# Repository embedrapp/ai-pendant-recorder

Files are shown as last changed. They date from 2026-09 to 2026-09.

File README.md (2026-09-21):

# AI Pendant Recorder

An open-source, privacy-first wearable audio recorder built around the Seeed XIAO ESP32S3. It records PDM microphone audio to removable microSD storage and uses a 5 × 5 RGB matrix for low-power status feedback.

## Hardware

- Seeed XIAO ESP32S3 **113991114** controller
- Infineon IM69D130 PDM microphone
- Molex 104031-0811 microSD socket
- MAX17048 fuel gauge and BMI270 IMU
- Regulated haptic output
- 25 × WS2812C-2020-V1 RGB LEDs
- Protected 500 mAh 1S LiPo design target
- No camera or speaker

## Schematics

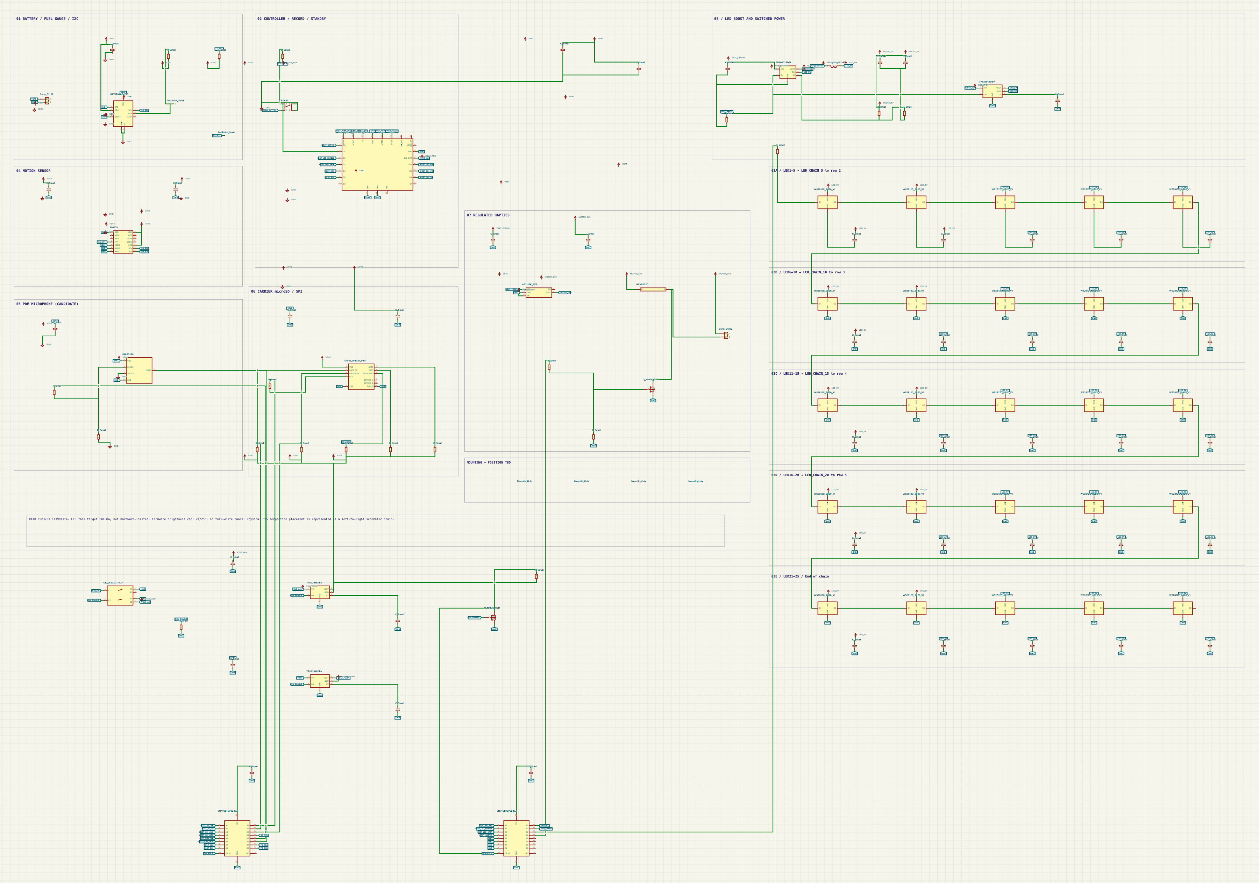
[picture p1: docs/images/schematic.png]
Full project schematic


The schematic is generated from [`pcb/ai_pendant_recorder.zen`](pcb/ai_pendant_recorder.zen) and is organized into battery/fuel-gauge, controller, motion, microphone, storage, haptics, LED power, and LED-row sections. Open the image for the full-resolution view.

## Board

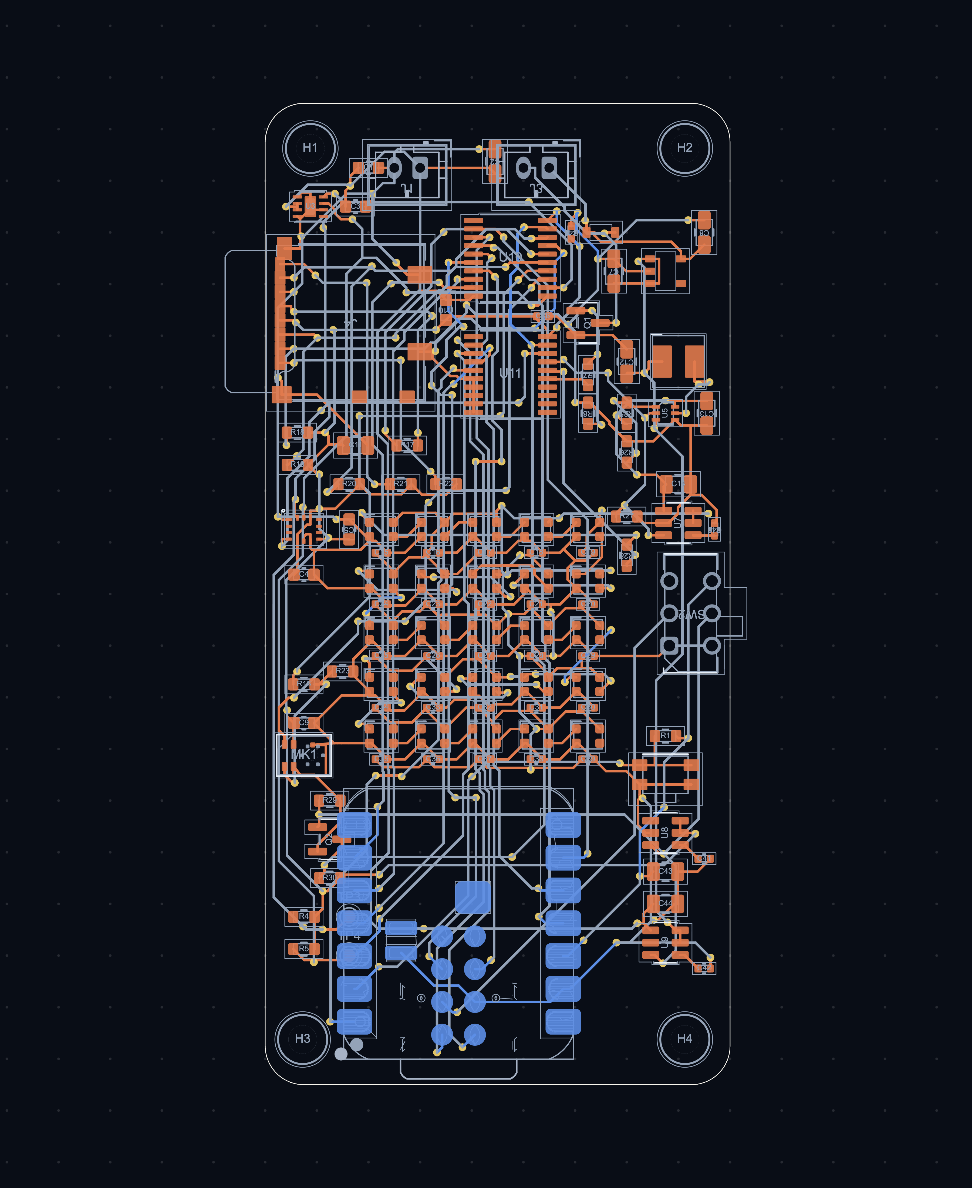
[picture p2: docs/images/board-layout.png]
Current PCB layout


The current four-layer KiCad board is in [`pcb/layout/layout.kicad_pcb`](pcb/layout/layout.kicad_pcb). It has a closed 36 × 76 mm rounded outline, four mounting holes, 115 footprints, 1,264 track segments, 200 vias, and no reported airwires.

Fresh checks on the current board:

| Check | Result |
|---|---|
| Zener source build | Pass — 115 components |
| ERC | Pass — 0 errors, 0 warnings, 79 style advice |
| KiCad DRC | **1 error**, 115 footprint-library configuration warnings |
| PDK-backed DFM | Pass — 0 findings |
| Firmware clean build | Pass for `seeed_xiao_esp32s3` |
| Enclosure CAD build | Pass — 16 valid solids |

The remaining DRC error is a 0.21 mm clearance between the IM69D130 acoustic opening and its surrounding ground pad, below the board-wide 0.25 mm hole-clearance rule. The geometry follows Infineon's recommended 0.8 mm sound port and SMD ground-pad land pattern, but the exception still needs an explicit KiCad rule or footprint-level resolution before the PCB checks are fully clean. The library warnings are caused by the standalone KiCad checker not loading the project-managed footprint libraries; they are not geometry violations.

## Mechanical design

### Pendant enclosure

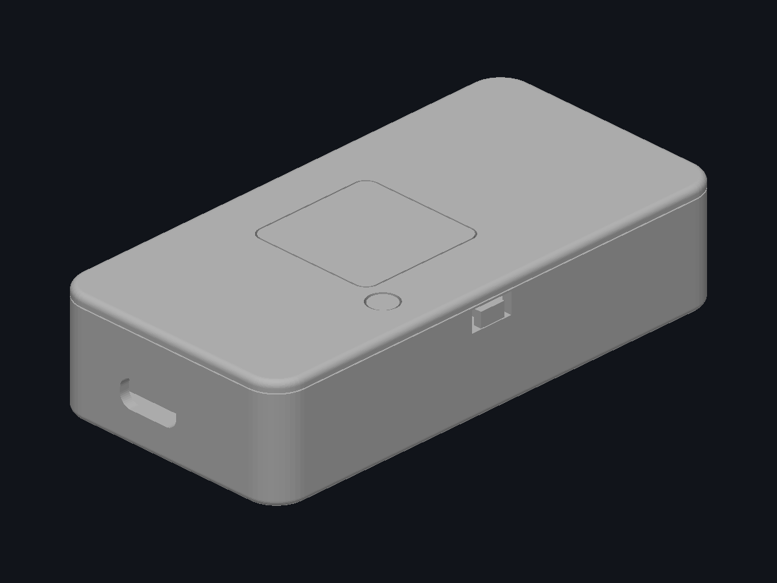
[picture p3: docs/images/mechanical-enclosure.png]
Pendant enclosure CAD


The parametric enclosure includes a rounded two-part shell, front optical area,
record-button opening, side controls/access, and lanyard loop. The latest STEP
build contains 16 valid solids and measures 40 × 87.785 × 18.2 mm overall,
including the loop.

### Populated PCB model

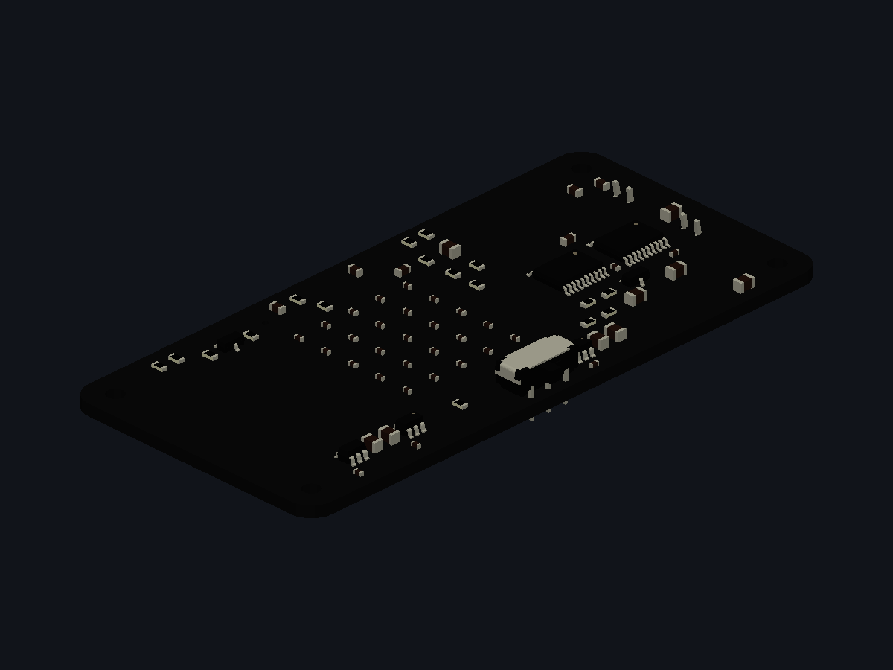
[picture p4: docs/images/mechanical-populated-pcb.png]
Populated PCB mechanical model


The populated-board model is used to coordinate PCB and enclosure geometry.
Some component models and exact interface heights remain incomplete, so the
render is a design aid rather than proof of interference-free physical fit.

## Firmware

The Arduino/PlatformIO firmware currently provides:

- push-to-toggle 16-bit PDM audio capture;
- chunked WAV recording to FAT32 microSD;
- recovery of interrupted `.part` recordings at startup; and
- conservative idle/recording animations on the RGB matrix.

Wi-Fi upload, fuel-gauge monitoring, motor activation, and automatic file deletion are not implemented.

### Build

1. Install [PlatformIO](https://platformio.org/).
2. Clone this repository and enter it.
3. Build the default environment:

   ```sh
   pio run
   ```

4. Connect a Seeed XIAO ESP32S3 and upload:

   ```sh
   pio run --target upload
   pio device monitor --baud 115200
   ```

Use a qualified FAT32 microSD card. Hardware pin assignments are documented in [`docs/current-design.md`](docs/current-design.md); setup notes are in [`docs/setup.md`](docs/setup.md).

## Repository map

| Path | Purpose |
|---|---|
| `src/main.cpp` | Recorder firmware entry point |
| `include/` | Shared firmware configuration and WAV helpers |
| `tests/` | Host-side audio-format test |
| `pcb/ai_pendant_recorder.zen` | Electrical and connectivity source |
| `pcb/layout/` | Current KiCad PCB and schematic |
| `pcb/bom.json` | Structured generated BOM |
| `docs/bom.md` | Human-readable procurement notes |
| `mechanical/` | Parametric enclosure source and current PCB STEP import |

## Engineering status

The current source, PCB, firmware, and enclosure generators are maintained together and were freshly built or checked. Remaining hardware work is tracked in [`docs/current-design.md`](docs/current-design.md), including the microphone DRC rule, power and charging validation, exact motor selection, enclosure interface dimensions, and physical bench testing.

## Contributing

Issues and pull requests are welcome. Keep changes focused, identify the hardware revision they target, and include validation evidence where practical. Do not commit credentials, private recordings, generated build directories, or unreviewed manufacturing outputs.

## License

This project is intended to be open source, but no license file is currently present. Until the maintainers add one, copyright law reserves reuse rights; please open an issue before redistributing or incorporating the design.

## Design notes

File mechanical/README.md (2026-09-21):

# Pendant enclosure

The maintained enclosure is generated from `pendant.py` using `pendant.cad.json`. It consumes the current board at `pcb/layout/layout.kicad_pcb`.

## Current geometry

Fresh cloud build and STEP inspection succeeded at revision `rev-db67b8b5fdb57ca66d4f7f5087f22955316bc1564d08ab42042626d73e8636f6`:

- 16 valid solids;
- overall measured bounds: 40 × 87.785 × 18.2 mm, including the lanyard loop;
- PCB frame: 36 × 76 × 1.62 mm with four 2.2 mm mounting holes;
- wearing orientation: lanyard at +Y, USB at -Y, LED face at +Z, and battery side at -Z.

The assembly includes the rear chassis, front cover, removable battery sled, optical cassette, 25-well optical baffle, record key, standby slider, acoustic gasket, and component reference envelopes. The detailed KiCad PCB STEP remains available as the separate `populated-pcb` mechanical design.

## Design assumptions

- PA12 additive manufacture is the current prototype process assumption.
- Battery envelope is 30.1 × 36 × 5.1 mm with 6.1 mm reserved thickness.
- USB and switch heights, mated connector/cable bends, antenna volume, exact motor package, and fastener selection are not yet established from complete manufacturer geometry.
- Four rear-access M2-class clearance bores and 1.6 mm blind pilot holes are modeled; screw length and pilot fit need a physical trial.

## Remaining fit validation

- Verify battery identity, swelling allowance, PCM and lead dimensions.
- Verify microSD insertion direction and the full card/finger access envelope.
- Verify USB plug overmold reach, switch travel, JST cable routing, and antenna clearance.
- Add or verify missing component 3D models and exact component heights.
- Check pairwise interference, tolerances, tool access, removal paths, enclosure closure, sealing, pull strength, and fatigue.
- Prototype the enclosure and perform an assembled hardware fit check.

A valid STEP build establishes solid geometry and measured bounds; it does not by itself establish tolerance, strength, sealing, or physical fit.

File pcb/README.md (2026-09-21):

# Electronics workspace

The maintained electrical source is `ai_pendant_recorder.zen`; the current physical board is `layout/layout.kicad_pcb`.

Sourcing metadata is stored in the source `PURCHASE_LINKS` / `DATASHEET_INDEX` maps and the persisted `bom.json` overlay. `bom.csv` is generated and should not be hand-edited.

## Board

- 36 × 76 mm rounded outline
- four copper layers, modeled at 1.62 mm total thickness
- 115 footprints
- 1,264 track segments and 200 vias
- no zones and no reported airwires

The source `Board(...)` points to `layout`, so there is one active board location. Regenerating or synchronizing a routed PCB is a deliberate board mutation; preserve and compare copper before doing so.

## Current checks

- Source build: pass, 115 components.
- ERC: pass, 79 style advice entries.
- DRC: one IM69D130 acoustic-hole/ground-land clearance error plus footprint-library configuration warnings.
- PDK-backed DFM: pass with no findings.

The microphone geometry follows Infineon's recommended 0.8 mm PCB sound port and surrounding solder-mask-defined ground land. Represent that intended geometry with a local KiCad rule or reviewed footprint change; do not weaken the global hole-clearance rule.

The four-layer stackup is a project model rather than a controlled-impedance fabricator stackup. Review boost current loops, trace widths, return paths, and the absence of copper planes before fabrication.

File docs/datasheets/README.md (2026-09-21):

# Datasheet evidence

Project document registrations are in `../../embedr.yaml`. Indexed documents
and exact part mappings are recorded in the Zen source. Local PDFs in this
directory support current components; check the manufacturer revision before
using them as procurement or production evidence.

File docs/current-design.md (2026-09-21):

# Current design status

The maintained design consists of:

- electrical source: `pcb/ai_pendant_recorder.zen`;
- current four-layer board: `pcb/layout/layout.kicad_pcb`;
- firmware: `src/main.cpp`; and
- enclosure generator: `mechanical/pendant.py`.

## Firmware and pin map

The firmware implements PDM recording to microSD and dim LED animations. Radio upload, fuel-gauge monitoring, and motor activation are not implemented.

| XIAO pin | GPIO | Function |
|---|---:|---|
| D0 | 1 | Motor gate |
| D1 | 2 | Record button |
| D2 | 3 | Boost EN / LED switch ON |
| D3 | 4 | LED data |
| D4 / D5 | 5 / 6 | I2C SDA / SCL |
| D8 / D9 / D10 | 7 / 8 / 9 | SD clock / MISO / MOSI |
| MTCK | 39 | SD CS |
| MTDO | 40 | IMU interrupt |
| MTDI / MTMS | 41 / 42 | PDM data / clock |

SW2 holds reset; it is not battery isolation. The battery design target is the protected Adafruit 1578 500 mAh 1S cell, documented with a 500 mA continuous discharge limit. The LED rail target is 100 mA rather than a hardware current limit. Brief dim animations must be coordinated with other loads; the firmware interlock is only partially implemented.

## Fresh validation

Checks were run against the current source and board:

- Zener build: pass, 115 components.
- ERC: pass with 0 errors, 0 warnings, and 79 style advice entries.
- KiCad DRC: 1 error and 115 footprint-library configuration warnings.
- PDK-backed DFM: pass with 0 findings.
- Board connectivity view: 1,264 track segments, 200 vias, and 0 airwires.
- Firmware clean build: pass for `seeed_xiao_esp32s3` / `esp32-s3`.
- Enclosure CAD: build and STEP inspection pass with 16 valid solids; measured bounds are 40 × 87.785 × 18.2 mm including the lanyard loop.

The DRC error is at MK1: the IM69D130's 0.8 mm acoustic opening is 0.21 mm from its surrounding GND land, below the board-wide 0.25 mm hole-clearance rule. Infineon's datasheet recommends the 0.8 mm PCB sound port and the surrounding solder-mask-defined ground land used by the footprint. The board still needs a deliberate footprint-specific KiCad rule or a reviewed footprint adjustment so this intended geometry is represented without a global clearance waiver.

The 115 DRC warnings report footprint libraries unavailable to the isolated KiCad checker. The footprints are embedded in the board and the Zener packages build successfully, so these warnings are configuration provenance warnings rather than reported copper or courtyard violations. They should still be eliminated from a final manufacturing handoff by packaging the library tables with the board export.

## Board and power

The PCB outline spans X=82..118 mm and Y=44..120 mm: 36 × 76 mm with 3 mm rounded corners and four 2.2 mm mounting holes. It is a four-layer board with a 1.62 mm modeled stackup. No copper zones are present, so the routed return paths require engineering review rather than assuming continuous reference planes.

U9 gates only the boost/motor branch (`VBAT_PERIPH`). J1, the XIAO battery input, and the fuel gauge remain on `VBAT`. SW2 carries control current only. USB charging remains connected; USB data operation is not promised while ESP32 EN is grounded.

## Remaining engineering work

- Resolve the microphone hole-clearance DRC rule locally and rerun DRC.
- Review boost hot-loop geometry, power widths, return paths, and four-layer stackup with the selected fabricator.
- Validate charger/regulator behavior, backfeed and power transitions on the bench.
- Select and verify the exact motor, including start/stall current and harness.
- Implement and test low-battery behavior, fuel-gauge monitoring, and haptics.
- Verify battery, USB, switch, connector, antenna, cable, and component-height clearances in a physical enclosure prototype.
- Perform audio, SD-write, thermal, charging, LED sequencing, and runtime recovery tests on assembled hardware.

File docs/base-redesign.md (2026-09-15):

# Superseded reference

Historical content: [archive](archive/pre-bom-finalization/base-redesign.md). Use [current BOM](bom.md), [LED contract](rgb-matrix.md), and the current Zen source. Historical checks do not release this revision.

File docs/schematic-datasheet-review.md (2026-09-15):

# Superseded reference

Historical content: [archive](archive/pre-bom-finalization/schematic-datasheet-review.md). Use [current BOM](bom.md), [LED contract](rgb-matrix.md), and the current Zen source. Historical checks do not release this revision.

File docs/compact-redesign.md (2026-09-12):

# Compact redesign — active engineering checkpoint

## RGB/haptic integration — newest checkpoint

The previous missing-RGB/haptic statements below are historical. Both circuits
are now integrated; see [rgb-haptics.md](rgb-haptics.md) for exact mapping,
datasheet corrections and remaining engineering limits. Source builds with 43
components/65 nets. ERC passes with 0 errors, 0 warnings, 70 naming-only advice
entries (`style.redundant_name`). Pin/net renderer inspection confirms separate
LED resistor nets, regulated motor positive, low-side Q1 and flyback polarity.
Screenshot review still finds long crossings and crowded labels; 29 rendered
envelope overlaps remain, with zero body overlaps. This is not drawing-readability
or physical-assembly acceptance. Existing board remains untouched, stale and
unrouted (33 DRC missing connections, two warnings). Firmware unchanged by request.

## Latest schematic validation checkpoint (supersedes older checkpoints below)

- Integrated bare BMI270 U4 and separate C4/C5 100 nF bypass capacitors.
  Local symbol/14-land footprint follows Bosch DS000-08 pp135,137,143,145.
  Both supply pins connect to 3.3 V; both grounds to GND; CSB high; SDO low;
  auxiliary and interrupt pins NC. Physical footprint review remains open.
- Corrected MAX17048 CELL to protected BAT+ following the manufacturer p6
  instruction, despite its internally unconnected implementation. Updated BOM.
- Package sync and source build pass: 24 components, 39 nets. Renderer pin
  inspection shows U1 D4/U3 SDA/U4 SDx on FG_SDA, U1 D5/U3 SCL/U4 SCx on
  FG_SCL, R4/R5 supply ends on V3V3. The screenshot's apparently floating
  pull-up rail is not a source disconnection, but its presentation needs repair.
- Independent check reports ERC 0 errors/0 warnings, 49 advice entries, all
  `style.redundant_name`. These are naming advice, not electrical failures.
  Existing unsynchronized physical board reports 33 missing connections and
  two warnings; it is NOT the new schematic's validated physical implementation.
- Schematic screenshots now work. Visual review still finds crowded labels,
  unreadable passive values and long crossings; after one broad placement pass
  the renderer reports 15 envelope overlaps (zero component-body overlaps).
- RGB indicators/PWM driver and regulated haptics remain missing. PCA9685PW
  assets and AO3400A package were obtained for evaluation, not integrated or
  approved as compact final selections. AP2112 library metadata gives suspect
  EN/GND numbering and must be compared to manufacturer data before use.
- Firmware/board remain unchanged and incompatible with AMP_ENABLE on D2.
  This is partial progress, not completion or assembly approval.

This redesign supersedes the camera-free direction in historical status notes.
Retain the exact XIAO Sense camera/microphone/microSD stack, bottom USB-C,
onboard charger, bare MAX17048 and BMI270, two RGB indicators, physical controls,
speaker, motor, shutter, and reinforced external loop. Firmware is not being
silently reverted to the original generic DevKit target.

## Constraints and acceptance

- Battery checkpoint: the active tray now targets stocked Adafruit product 1578,
  a protected 1S 3.7 V 500 mAh pack with JST-PH. CAD reserves a conservative
  30.1 x 36.0 x 6.1 mm envelope (5.1 mm maximum documented body plus 1 mm
  expansion allowance). See `mechanical/front-battery-notes.md`. This supersedes
  the older 34 x 50 x 6 mm provisional tray statements below; purchase and
  electrical/thermal validation remain open.
- Compactness is a priority, but no final envelope is accepted yet. The selected
  battery body is approximately 30 x 36 x 5 mm; the old 26 × 42 mm tray cannot fit it.
- Start with two copper layers and top-side assembly; reconsider sides only with
  explicit battery, solder-tail, and module-stack clearance checks.
- Preserve the existing board before synchronization. Initial board SHA-256:
  `603e4063f2eb6049fc6aba0b6d4d31e2fab530e9a42179f2f1ad86a098743166`.
  Inspection found 15 footprints including four holes, no tracks/vias/zones,
  and screenshot reported 33 airwires. Existing locks are not placement approval.
- Keep an antenna wall zone and cable bend space clear of battery, copper,
  speaker/motor magnets, fasteners, and attachment hardware. Target 3–5 mm
  electronics clearance subject to assembled RF tests.
- Printed modules: rear shell, front shell, replaceable shutter and retainer,
  removable battery tray, speaker retainer, motor cradle, light-port inserts,
  optional clothing backer. Final process/tolerances remain to be validated.
- Acceptance requires source/netlist review, visual schematic review, placement
  geometry and images, ERC/DRC/DFM, current assembly STEP interference and service
  path checks, and printed/hardware validation. No release claim from a build.

## Findings to resolve before layout freeze

1. U3/U4, RGB LEDs, haptic circuit, J3 and new support parts are absent from Zen.
2. C1/C2 sourcing differs from the procurement BOM. R3 is amplifier-enable series
   resistance in the source, not an LED resistor. The price table counts four
   100 kΩ resistors for R1/R2/R8 although those references total three.
3. RGB channels require six current-limiting resistors and a GPIO/PWM budget;
   do not allocate camera, microphone or microSD pins to these functions.
   A shared-I2C PWM driver may be needed and would be a documented BOM addition.
4. QX-1027 is rated 2.5–3.5 V (datasheet p3), 85 mA running maximum and 230 mA
   starting/locked maximum at 3 V (p4). Direct 4.2 V BAT+ is not approved.
   Resolve a regulated motor supply and transient/current budget; PWM alone is
   not proof of voltage compatibility. D1 cathode must follow MOTOR+.
5. Superseded: the retained NOVA/LiPol three-wire drawing is no longer the active
   tray basis. Adafruit 1578 is the selected two-wire JST-PH protected candidate;
   delivered-pack polarity, PCM details, shipping and sample metrology remain gates.
6. The retained motor drawing is QX-1027-3.0-07, not proof of the Robu part.
   Model it as a reference variant, not a confirmed purchased component.
7. SW1 GK has neither pegs nor the ESD pin. Use the exact variant in its model.
8. Seeed retained datasheet p6 gives 21 × 17.8 × 15 mm with expansion board;
   the existing enclosure's assumed 10 mm stack is not accepted for this redesign.

## Local reference provenance

- PTS841 PDF SHA-256: `7c9c6ab89d64f98dcc287a2646c8fdceb7bc00973e170807c5de820f69a716bf`, p2.
- LiPol PDF SHA-256: `46d1f33d6de0c5ff81b80471a1f5973744574150349fc1152e5967f51f017052`, p1.
- QX motor PDF SHA-256: `636a2f1f12dba6d8a8be3817c067e20b3dcb9d23b5924e11af8e5077d5cb5a22`, pp3–4,9.

Status: inspection/reconciliation in progress; final assembly is not validated.

## Implemented checkpoint

### Schematic update checkpoint

Added U3 MAX17048 polling circuit, C3 bypass, R4/R5 shared 3.3 V I2C pull-ups,
and TP3/TP4. D4/D5 now carry I2C; AMP_ENABLE moved to D2. Existing firmware
and physical board are NOT synchronized to that pin change and must not be used
as a matched revision. Camera/microphone/microSD remain internal to U1.

Sync and root build passed with 21 components; netlist inventory inspected.
U3 uses the materialized library footprint provisionally: its description cites
an ST DFN package, so comparison with ADI land pattern 90-0065 is a release gate.
The datasheet pin table calls CELL internally unconnected but also says connect
to battery; this draft retains the BOM's NC choice pending reconciliation.

Saved agent-chosen positions for all 21 schematic components. Renderer reports
zero body overlaps but 15 rendered overlaps (including power symbols and labels).
Both screenshot attempts returned blank images despite nonzero component/wire
counts. Visual review is blocked; no schematic-readability acceptance is claimed.
BMI270, RGB indicators/PWM support and regulated motor circuit are still absent.
The full original-plan schematic request is not complete.

- C1/C2 Zen MPNs now match bom.md. Obsolete supplier SKUs were removed rather
  than transferred to different parts. Automatic lint/evaluation and the managed
  root build passed (15 components). No board regeneration or physical move ran.
- MAX17048 symbol/footprint assets materialized with provenance; wrapper and
  fixture validation are still pending. These are not yet integrated into Zen.
- Three preliminary reference STEP exports were cloud-built after repairing
  the Compound construction. All passed inspectable-solid checks only:
  - BAT1: `mechanical/components/bat1-reference/bat1-provisional-envelope.step`,
    revision `rev-31d573a35125bc3859d77bfbb0df98f03f3f52e703582cbb0b0603a178b34017`.
  - M1: `mechanical/components/m1-reference/qx-1027-reference-envelope.step`,
    revision `rev-04c4ff6a515c47ffbbf41770e17c54fde9752942c8d631e716872e359b7e279b`.
  - SW1: `mechanical/components/sw1-reference/pts841gk-body-only.step`,
    revision `rev-3d8be8e52fd355475e70c1d510022c33aa46fd0339a5aa678c6197930127afcf`.
- These are envelope references, not completion of the three detailed CAD gaps.
  SW1 actuator/leads, motor lead exit and purchased battery details remain open.
- Still required: complete GPIO/PWM allocation and motor supply, exact new part
  packages, all BOM support components, schematic layout, compact board outline
  and reviewed placement, modular enclosure/shutter, all-component assembly
  transforms and interference/service sweeps, electrical and printed validation.

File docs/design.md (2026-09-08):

# AI Second Brain pendant — engineering record

The exact XIAO ESP32S3 Sense (SKU 113991115) provides the ESP32-S3, digital microphone, camera connector, and microSD socket. The local MAX98357AETE+T wrapper provides I2S speaker output with 100 nF and 10 uF bypass capacitors. Firmware separates recording and upload FreeRTOS tasks; 15-second chunk files remain local when Wi-Fi is unavailable.

The microphone is the integrated PDM microphone on U1's Sense expansion board: GPIO41 is PDM data and GPIO42 is PDM clock. It is not a separate PCB footprint. Firmware initializes it through Arduino `I2S` in mono PDM mode at 16 kHz/16-bit.

Open hardware decisions: protected LiPo vendor/MPN and dimensions; exact 8-ohm speaker MPN, diameter, thickness, and acoustic volume; final slide switch and battery mating lead; hard EN power-isolation circuit; PCB outline, magnet, standoffs, and enclosure dimensions. The first concept assumes a protected 3.7 V 500 mAh cell.

The DevKitC-1 firmware target is compatibility-only because the installed target catalog has no exact XIAO target. The current firmware is a buildable scaffold, not a completed cloud protocol implementation.

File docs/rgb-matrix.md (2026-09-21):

# Central 5x5 RGB matrix

The speaker-output chain is removed. The board now has a square 5x5 matrix of
25 Worldsemi `WS2812C-2020-V1` addressable RGB LEDs, intended for the visual
thinking/orbit animations in the supplied reference image.

## Electrical implementation

- LED1–LED25 form one 800 kbit/s GRB daisy chain. XIAO D3/GPIO4 drives the
  first pixel through R28 (470 ohm).
- U5 TPS61023 boosts protected `VBAT` to `BOOST_5V` using the TI reference values:
  L1 1 uH, R25 732k, R26 100k, C12 10 uF input, C13/C14 22 uF output.
  The divider gives 4.95 V at the 595 mV typical FB reference
  (`0.595*(1+732/100)`), approximately 4.83–5.08 V across the datasheet's
  580–610 mV PWM reference limits before resistor tolerance. This remains
  inside the LED's documented 3.7–5.3 V operating range.
- U7 TPS22918DBVR switches `BOOST_5V` to the pixel `LED_5V` rail. Its ON pin
  shares XIAO D2/GPIO3 with U5 EN, R27 holds both off through reset, C40=1 nF
  C0G sets about 2.9 ms nominal 5 V rise time, and QOD is tied to `LED_5V` for
  defined discharge. C13/C14 remain on the boost side; per-pixel bypass is on
  the switched side. Firmware holds DATA low before enabling the rail.
- Each pixel has a local 100 nF 0402 capacitor (C15–C39), as required by the
  Worldsemi typical application.

The exact LED is the low-current 5 mA/channel `WS2812C-2020-V1`, LCSC
`C2976072`. Its documented operating range is 3.7–5.3 V and VIH is at least
2.7 V at 5 V, so the XIAO's 3.3 V GPIO directly satisfies the specified input
threshold. Package pinout is DO1, GND2, DI3, VDD4.

## Power limits

The selected Adafruit 1578 / PKCELL protected 500 mAh pack is limited to 1C,
or 500 mA maximum continuous discharge. A theoretical 25-pixel full-white
frame is 375 mA at 5 V before quiescent and conversion losses, which exceeds
the battery budget once the XIAO, storage, microphone, and motor are included.
Firmware must apply a conservative global brightness/current cap, avoid
full-white frames, and inhibit high LED load during motor start. This is an
acceptance requirement, not yet a bench-verified current limit.

Current firmware uses an Adafruit NeoPixel global brightness cap of 24/255,
lights at most five pixels in the recording pulse and one pixel in the idle
orbit, and keeps the haptic gate low by default. The cap is a conservative
software guard, not a substitute for measuring battery, boost, switch and PCB
temperature at minimum battery voltage and worst-case card-write load.
The confirmed product target is no more than 100 mA on the 5 V LED rail.

## Physical intent

### LED-control implementation update

- Animator alone owns data and rail switching after setup. Storage faults request
  FAULT instead of cutting power concurrently with a transmission.
- Startup holds data low, enables the rail, waits a provisional 10 ms, sends
  black, and waits 2 ms before animation. Shutdown sends black, holds data low,
  waits 2 ms, then removes power; no transmissions occur while powered off.
- The 24/255 cap and one/five-pixel animations remain. Recording output is halved
  conservatively for SD load. LED_INHIBIT/LED_OFF provide a request/acknowledgment
  contract for future motor control; HEAVY_LOAD dims future radio activity.
  Motor and radio activity are not currently implemented.
- Low-battery automatic inhibition is NOT implemented: the fuel-gauge driver and
  measured cutoff/recovery thresholds remain required. Do not invent a voltage
  threshold or treat firmware as enforcing measured 100 mA rail current.
- The schematic now reads as five left-to-right rows, preserving exact chain
  connectivity. Physical layout, copper, and component selection are unchanged.
- The configured firmware target is the Seeed XIAO ESP32S3. The clean firmware
  build passes; hardware behavior still requires bench validation.

Place the LEDs as a geometrically regular 5x5 square at board center, with
uniform pitch and identical orientation. Place each bypass capacitor directly
beside its pixel. Keep U5/L1 and their high-current switching loop outside the
microphone acoustic/clock area. The current board uses a regular 5x5 placement;
verify alignment against the enclosure light guide on the physical prototype.

## Evidence

- WS2812C-2020-V1 indexed datasheet: `ds_f7eaed7171762f8cbf8e`
- TPS61023 indexed datasheet: `ds_c3d679f9c6eab3a775cd`
- TPS22918 indexed datasheet: `ds_61aa790c3c3008f98c5e`
- Adafruit 1578 / PKCELL pack: `ds_dcee32f4e0c985211bc8`
- XEL4030 family: `ds_293e09d408f8109bb968`

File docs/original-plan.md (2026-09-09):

# AI Second Brain Pendant — Updated Product Plan

This file records the current product direction. It supersedes the original
camera-based XIAO ESP32S3 Sense-stack concept. Existing PCB, firmware, and
mechanical artifacts still represent earlier revisions in places; this plan is
not evidence that the redesign has been implemented or validated.

## Product goal

Build a thin, tall, narrow wearable audio recorder centered on:

- High-quality voice capture.
- Reliable local storage.
- USB-C programming and single-cell LiPo charging through the controller board.
- Battery percentage reporting.
- Motion/context sensing.
- Optional local speaker playback and haptic feedback.

The camera is no longer a requirement. Remove the camera, camera connector,
camera apertures, privacy shutter, camera power rails, image capture firmware,
and image-upload backend requirements.

## Confirmed architecture

- Use the **base Seeed Studio XIAO ESP32S3 board**, without the Sense camera/SD
  expansion board.
- Preserve the XIAO's working ESP32-S3, flash/PSRAM, USB-C programming, onboard
  LiPo charger, boot/reset circuitry, and Wi-Fi/BLE antenna implementation.
- Create a thin custom carrier PCB that reproduces only the functions needed by
  this product: digital microphone, storage, sensors, indicators, audio, and
  haptics.
- Do not mount the XIAO on pin headers. Use low-profile direct soldering or a
  recessed/cutout arrangement after verifying accessible pads and assembly
  clearances.
- Keep the battery, XIAO, speaker, and motor in separate XY regions where
  possible. Do not stack the PCB or tall components over the LiPo pouch.
- Keep the speaker and vibration motor for the first integrated prototype;
  remove either only if measured fit, runtime, acoustic, or peak-current results
  require it.

## Controller and USB

- Confirm the exact orderable base-XIAO part identity and its current schematic,
  pad map, dimensions, and antenna requirements before changing the PCB source.
- Use the XIAO USB-C connector for both programming and charging.
- Retain access to boot/reset and provide production test points where practical.
- Do not drive USB VBUS from another 5 V source.
- Treat the onboard charger as a simple charger, not a full power-path manager.
  Measure whether the system can operate and charge acceptably at the same time.
- If authoritative charge/full/fault reporting becomes mandatory, a later
  revision may need a dedicated charger/power-path IC with status outputs.

## Audio capture

- Select an exact low-profile digital PDM MEMS microphone intended for voice:
  target at least 65 dBA SNR, preferably 68–70 dBA, high acoustic-overload
  capability, low sleep current, and 1.8–3.3 V operation.
- Do not automatically reuse the Sense-board microphone. Compare exact,
  procurable candidates using indexed manufacturer datasheets and install the
  chosen component with a verified symbol, footprint, and acoustic-port data.
- Start with one microphone. Add a second only if beamforming/noise-rejection
  requirements justify the extra spacing, power, DSP, and acoustic validation.
- Give the microphone a short dedicated sound port, perimeter gasket, and dust
  mesh. Keep it away from the speaker, motor, buttons, USB opening, switching
  currents, and enclosure leakage paths.
- Validate microphone SNR, clipping, self-noise, mechanical noise, and speech
  intelligibility on assembled hardware; schematic checks cannot validate
  acoustic performance.

## Storage

- Put a low-profile microSD socket and its required support circuitry directly
  on the custom carrier.
- Verify the exact GPIO mapping and bus sharing against the base XIAO schematic;
  do not infer mappings from Arduino aliases or the removed Sense expansion.
- Keep FAT storage, atomic file finalization, recovery scanning, and buffered
  writes.
- Prefer batched, aligned writes to reduce latency and energy use.
- Reconsider soldered flash/eMMC only if removable storage is unnecessary and
  the microSD socket becomes a thickness or reliability blocker.

## Sensors and user interfaces

- Retain the **MAX17048** for LiPo voltage and state-of-charge percentage over
  I2C. Its charge-rate estimate may indicate probable charging but is not an
  authoritative charger-status signal.
- Retain the **BMI270** for motion, wear/activity context, and wake behavior;
  use its low-power modes when possible.
- Consider a battery NTC/ADC input if the final pack exposes a documented
  thermistor.
- Retain physical record and standby controls. Do not add capacitive touch.
- Use subtle, low-current status indication. Prefer direct MCU control or a
  smaller LED solution over the PCA9685 unless the final channel count truly
  requires that device.
- Retain MAX98357A-based differential speaker drive only with a verified speaker,
  explicit gain/power limits, shutdown control, and acoustic design.
- Retain the MOSFET-driven haptic motor with gate pulldown, flyback protection,
  and a source rated for measured start/stall current. Never drive it directly
  from a GPIO.

## Battery direction

Battery selection remains open and must be based on a finished protected-pack
drawing, not the nominal pouch size code alone.

For a tall, narrow product, search for a traceable 1S LiPo pack with:

- Approximately 300–500 mAh, subject to measured runtime.
- Finished width preferably 11–18 mm.
- Finished thickness preferably no more than 4–5.5 mm.
- Length selected around the tall enclosure, approximately 45–65 mm.
- Integrated PCM or a separately designed protection circuit.
- 4.20 V charge compatibility with a documented allowed charge current.
- At least 500 mA continuous discharge and a documented higher pulse rating, or
  measured limits that support enforced load scheduling.
- Preferably a 10 kΩ NTC, plus IEC 62133/IS 16046 and UN38.3 evidence for the
  exact pack.

The WLY601145 300 mAh pack may be used for an early narrow prototype, but its
finished maximum envelope is approximately 6.5 × 11.5 × 47.5 mm. It therefore
implies a thicker enclosure and is not the preferred final thin-pack choice.
Do not accept unverified high-capacity marketplace claims without a manufacturer
datasheet, finished dimensions, protection details, and discharge test results.

Before schematic freeze, calculate and then measure simultaneous peak demand
from ESP32 radio activity, SD writes, speaker output, and motor startup. If the
pack cannot support overlapping peaks, enforce load scheduling in firmware and
document those prohibited combinations.

## Power and runtime strategy

Removing an inactive camera mainly improves thickness and removes unused rails;
the largest runtime gains must come from power management:

1. Keep Wi-Fi off during ordinary recording and batch uploads later.
2. Shut down the speaker amplifier except during playback.
3. Enable the motor rail only for short haptic events.
4. Run the BMI270 and microphone in the lowest modes compatible with behavior.
5. Turn indicators off quickly and use low PWM current.
6. Buffer microSD writes rather than issuing frequent small transactions.
7. Reduce ESP32 clock/peripheral activity when workload permits.
8. Use deep sleep when the product is neither recording nor synchronizing.

Create an operating-state current budget for off, standby, recording, playback,
haptic, upload, and USB-connected operation. Capacity and runtime claims require
bench measurements on the assembled prototype.

## Firmware plan

- Use the managed `seeed_xiao_esp32s3` target and preserve credentials outside
  source control.
- Separate recording and upload work with bounded buffers/queues.
- Store recoverable WAV/PCM chunks and finalize files atomically.
- Support offline recording, bounded upload retries, provisioning, TLS, and
  reconnection.
- Read MAX17048 voltage/SOC and expose a clearly qualified probable-charging
  state only when supported by USB presence and charge-rate evidence.
- Use BMI270 interrupts/low-power modes for context and wake behavior.
- Add explicit power-state control for microphone, SD, amplifier, motor, LEDs,
  and radio where hardware permits.
- Remove camera initialization, capture, image upload, image-description, and
  camera privacy-control code and configuration.
- Retain voice-question/TTS and optional Home Assistant integration only as
  secondary features behind stable recording and storage.

## Mechanical direction

- Target a smooth, tall, narrow pendant rather than widening around a large
  battery.
- Begin with a 0.8 mm carrier PCB and a recessed/direct-mounted base XIAO.
- Align the XIAO USB-C connector with an enclosure opening.
- Reserve the full antenna body and feed geometry against a plastic wall, away
  from battery, copper, speaker magnet, motor, and metal attachment hardware.
- Provide microphone port/gasket/mesh, speaker grille, microSD service access,
  physical controls, and a reinforced external attachment loop.
- Keep the battery in its own supported cavity with swelling allowance, wire
  strain relief, insulation, and no sharp or compressive features.
- Use exact maximum component and pack envelopes before accepting enclosure
  width, length, or thickness. An 8 mm finished thickness is not assumed.

## PCB redesign sequence

1. Preserve the existing board and source as the prior prototype revision.
2. Confirm the exact base XIAO schematic, dimensions, pads, USB, charging, and
   antenna constraints.
3. Select and datasheet-verify the microphone, microSD socket, battery, speaker,
   motor, controls, and all exact footprints.
4. Revise the Zener source to remove the Sense/camera expansion and camera-only
   circuitry, then add the custom microphone/storage interfaces.
5. Reassess GPIO allocation, boot straps, shared buses, startup states, I2C
   pull-ups, decoupling, shutdowns, and test points.
6. Build and inspect the exact netlist; perform a fresh datasheet pin/strap and
   electrical-limit review.
7. Create a new board revision rather than destroying the existing routed
   artifact. Review mechanical anchors, antenna keepout, acoustic zones, battery
   cavity, connector access, and current loops before routing.
8. Route and review return paths, power integrity, SD and PDM signals, audio
   current loops, motor noise, and RF clearances.

## Acceptance and validation

The revised product is not ready until all applicable evidence is complete:

1. Manifest and firmware-target validation.
2. Zener build, exact netlist inspection, and independent ERC.
3. Datasheet-grounded review of every IC and selected pack.
4. Verified symbols, pad numbering, footprints, and package dimensions.
5. Whole-board placement review, routing review, DRC, and DFM.
6. Firmware build plus hardware tests for recording, file recovery, upload,
   battery reporting, controls, sensor behavior, speaker, and haptics.
7. Current and runtime measurements in every operating state, including USB
   charging while operating.
8. Microphone acoustic testing in the final enclosure.
9. Enclosure STEP inspection with battery swelling, antenna, USB, microSD,
   acoustic, control, and assembly clearances.
10. Fabrication and assembly exports generated from one accepted revision.

Cloud services, RF range, acoustic quality, battery safety, charging behavior,
and real runtime require physical hardware validation; successful source builds
or schematic checks alone do not establish them.

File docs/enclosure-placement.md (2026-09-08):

# Compact mechanical/placement revision

Candidate carrier: 44 × 60 mm R3, two copper layers, top-side components.
Shell target: 50 × 70 mm excluding loop, full 15 mm Sense stack above PCB,
protected 603450 battery behind PCB in a removable tray. No claim of minimum
possible size: battery, connector access and full Sense assembly dominate.
Bottom-facing USB-C: U1 rotated 180 degrees. Mount holes at ±19/±27 mm.
Rear battery clearance keeps solder tails away from the pouch; no compressive
retention. Upper side antenna zone and detachable front/shutter modules.
Material assumption: PETG, 0.4 mm nozzle, 0.2 mm layers; trial-fit gap 0.3 mm.
Exact purchased battery PCM/lead exit, motor identity, antenna and optical port
datums remain measurement gates. Existing board/CAD retained under backups/archive.

## Current evidence / unfinished acceptance

All 43 footprints synchronized and manually positioned on the 44×60 R3 carrier.
Inspection reports zero same-side rendered-envelope intersections. U1's USB/body
graphic intentionally extends 0.547 mm past the bottom; its solder pads remain
inside. Rounded Edge.Cuts are not supported by the placement containment checker,
so its unknown findings are NOT a containment pass. Board screenshot reviewed;
central silkscreen remains crowded. No copper routing performed (107 airwires).
Source comments persisted from the inspected coordinates after the placement-comment
tool failed footprint resolution; LSP lint timed out, evaluator passed.

Fresh ERC passed with 70 naming advice. DRC: 107 unconnected findings plus eight
0.15 mm RGB pad gaps below the board's 0.16 mm rule, and 38 warnings. Do not
blindly enlarge these tiny manufacturer lands or lower global clearance; review
an appropriate fabrication profile and scoped same-package rule before routing.
No placement freeze, manufacturing approval or all-component fit acceptance yet.

Enclosure source `mechanical/compact-pendant.py`, active `pendant.cad.json`.
Cloud revision `rev-699a1b13bb7f50bbd056d08ae395d6df121b9782dba1ac015158a79c486cc6ac`
contains nine inspectable solids; exported to
`mechanical/exports/compact-pendant-fit-prototype.step`.
Shell body 50×70×33 mm; total modeled bounds 51×76.5×39.5 mm including loop,
backer, shutter and light inserts. Only valid-solid checks passed, NOT interference.
The exact electronic STEP components are not assembled into this revision.
Optical/USB/SD datums, antenna size/bend relief, plunger detail, shutter full-open
travel/frame attachment, magnet retention, tray retention and print orientation
still need refinement. Legacy individual-part manifests still point at old CAD;
use only the active pendant design for this candidate. This is a fit prototype,
not a completed enclosure or print-ready set.

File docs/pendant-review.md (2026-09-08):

# Pendant revision: edge controls and restrained shell

Preserve 43-part electrical design, 1-cell battery, existing 3.3 V interfaces and two copper layers. No new parts or copper removal. Existing board is unrouted. All components are on FRONT (the module is at the bottom edge, not on bottom copper).

44 x 60 mm closed R3 board; target shell 49 x 65 mm. Four M2 mounts constrain corner radii. Retain PETG prototype process and 0.3 mm mating clearance. Existing 34 x 50 x 6 mm provisional cell and 15 mm Sense stack prevent an honestly ultra-thin case without changing hardware.

SW1 local +Y actuator rotated 90 degrees faces board +X; actuator tip at X122.0, exactly the right board edge. SW2 shifted to X117.4: outward actuator overhang intentional, outer pad center X120.7 retained inside X122 edge. D2/D3 unchanged at X79.2, Y90/94; top-emitting LEDs need front-directed light guides.

Acceptance: source build; explicit schematic positions and visual review; current-board screenshot; closed outline and pad clearances; fresh checks; cloud STEP solid and interference checks; assembled and cutaway images. Unknown heights, USB plug/port datums, button stroke/force, battery PCM/lead exit and motor identity remain measurement gates. Renderer collisions must not be described as a clean schematic.

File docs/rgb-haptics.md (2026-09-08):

# RGB/PWM and regulated haptics circuit

Implemented in `pcb/ai_pendant_recorder.zen`; firmware and physical board unchanged.

## Connections and operation
- U5 PCA9685PW,118 at I2C 0x40, all six address straps low; shared R4/R5
  pull-ups only. Internal clock (EXTCLK grounded), OE grounded, 3.3 V supply/C6.
- PWM0–2 = LED1 R/G/B, PWM3–5 = LED2 R/G/B. Exact Kingbright
  APGF0607G32B33R23-05 common-anode LEDs, anodes at V3V3. Six 2 kΩ
  resistors R9–14 limit instantaneous current to <1.7 mA even with zero Vf.
  Actual blue/green current and visibility near 3.3 V require bench testing.
  Push-pull output mode is required: low lights LED, high extinguishes it.
  POR outputs are low, so LEDs initially illuminate at resistor-limited current;
  they are NOT guaranteed dark or a trustworthy recording indication before init.
- PWM6 drives Q1 through R7=100 Ω; R8=100 kΩ gate-to-ground. High runs motor.
  Use the common PWM frequency within PCA9685 limits (e.g. 1 kHz); motor noise,
  switching loss and optical flicker require bench review.
- D0/GPIO1 independently arms U6 AP2112K-3.3TRG1; R15=100 kΩ defaults off.
  U6 is supplied from protected BAT+, not the XIAO 3.3 V rail. Its 3.3 V output
  feeds J3 pin1; pin2 is Q1 drain. D1 cathode is MOTOR_3V3, anode Q1 drain.
  Initialize PWM6 low before arming. Disarm on stop/fault/standby; reset's
  high-impedance GPIO allows R15 to disable supply even if PWM registers persist.
- C7/C8 10 µF input/output bypass; ensure >1 µF effective after DC bias/tolerance.
  No battery charger was added. D8–D10 and Sense internal pins untouched.

## Grounding and corrections
- Kingbright local datasheet SHA256 43d8fc8d3f7e39f0f9c21c2bf722aae6e65334d89e6bc0cbe2543b41e386283e,
  p1: pin1 anode, 2 green, 3 blue, 4 red; 0.25 mm lands with 0.15 mm gaps.
  Stencil 80% open area/80–100 µm is a manufacturing gate, not yet enforced.
- PCA9685 indexed ds_b09c802523b445b70995 chunks 12–14,49: TSSOP pins
  LED0=6, VSS=14, OE=23, A5=24. Published library symbol metadata was WRONG;
  private corrected symbol used, original retained unused. Package footprint reused.
- AP2112 indexed ds_6ea4cad5e5943d92f8bb chunks 4,35: VIN1/GND2/EN3/NC4/VOUT5.
  Published library EN/GND numbering was WRONG; private symbol and manufacturer
  suggested lands used. Regulator is 600 mA rated, subject to thermal limits.
- onsemi retained datasheet p1,3: NSVR0320MW2T1G K1/A2; lands 0.63×0.83 mm,
  centres 2.23 mm apart. Diode dissipation limit 200 mW at 25°C must be respected.
- Q1 uses the installed exact AO3400A package and G1/S2/D3 mapping.
  Asset generation is reproducible with `pcb/components/generate_indicator_assets.py`.

## Limits and acceptance

Validation run: package sync, managed root build (43 components), exact netlist
inventory (65 nets), renderer pin/net inspection, schematic screenshot and ERC.
ERC: zero errors/warnings; 70 redundant-name style advice. Drawing remains
visually draft with label overlaps. The untouched old board fails DRC and must
not be fabricated as this circuit. No runtime, thermal or motor-load test ran.
Motor selection remains the BOM's Flat 1027 candidate; Robu URL discrepancy
is not resolved by this circuit. Nominal 3.3 V avoids direct 4.2 V battery drive.
QX reference starts at up to 230 mA at 3 V; at 3.3 V allow approximately 260 mA
for preliminary budgeting, not a verified maximum. U6 nominal dissipation is
about (4.2−3.3)×0.26=0.234 W during start; copper/temperature and stalled-motor
tests are required. Dropout at depleted battery may reduce vibration or prevent
starting. Firmware must bound haptic pulse duration and disable at low battery.
Neither LDO current limit nor MOSFET rating is a substitute for motor stall protection.

No new exact STEP models for U5/U6 or physical placement are claimed. TSSOP28
is a larger but inspectable prototype driver, not proof of minimum board area.
Review all custom footprints, assembly tolerances, shared bus current, rail
transients, RF/audio coupling, startup behaviour and LED visibility before release.

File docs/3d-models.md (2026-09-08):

# Component STEP / 3D-model manifest

Checked 2026-09-08 IST. This manifest covers every purchased, development-only, and non-purchasable component called out in [bom.md](bom.md). Local files are sourced downloads only; no STEP geometry was created for this task. There is one retained CAD asset per unique component/package identity; repeated BOM references point to the same retained file.

`PASS` means the local download passed file-level STEP checks: ASCII STEP header and terminator plus BREP/closed-shell entities. It is not a claim that a generic package model reproduces every manufacturer-specific detail. `UNRESOLVED` means no usable source file was found or access was gated; the empty model path is deliberate.

## Local models

| Ref / component | Local STEP file | Match | Validation | Source |
|---|---|---|---|---|
| U1 — Seeed XIAO ESP32S3 Sense, 113991115 | [seeed-xiao-esp32s3-sense-113991115.step](../mechanical/components/seeed-xiao-esp32s3-sense-113991115/seeed-xiao-esp32s3-sense-113991115.step) | Exact manufacturer assembly | PASS | [Seeed 3D-model ZIP](https://files.seeedstudio.com/wiki/SeeedStudio-XIAO-ESP32S3/res/seeed-studio-xiao-esp32s3-sense-3d_model.zip) |
| U2 — MAX98357AETE+T | [max98357aete-t-tqfn-16-3x3mm.step](../mechanical/components/max98357aete-t/max98357aete-t-tqfn-16-3x3mm.step) | Generic exact TQFN-16 / 3 × 3 mm package | PASS | [KiCad TQFN-16 STEP](https://raw.githubusercontent.com/KiCad/kicad-packages3D/master/Package_DFN_QFN.3dshapes/TQFN-16-1EP_3x3mm_P0.5mm_EP1.6x1.6mm.step) |
| U3 — MAX17048G+T10 | [max17048g-t10-dfn-8-2x2mm.step](../mechanical/components/max17048g-t10/max17048g-t10-dfn-8-2x2mm.step) | Generic exact 8-DFN / 2 × 2 mm package | PASS | [KiCad DFN-8 STEP](https://raw.githubusercontent.com/KiCad/kicad-packages3D/master/Package_DFN_QFN.3dshapes/DFN-8-1EP_2x2mm_P0.5mm_EP0.7x1.3mm.step) |
| U4 — Bosch BMI270 | [bosch-bmi270-lga-14-3x2.5mm.step](../mechanical/components/bosch-bmi270/bosch-bmi270-lga-14-3x2.5mm.step) | Generic exact Bosch LGA-14 / 3 × 2.5 mm package | PASS | [KiCad Bosch LGA-14 STEP](https://raw.githubusercontent.com/KiCad/kicad-packages3D/master/Package_LGA.3dshapes/Bosch_LGA-14_3x2.5mm_P0.5mm.step) |
| SPK1 — Same Sky CMS-16093-078L100 | [same-sky-cms-16093-078l100.step](../mechanical/components/same-sky-cms-16093-078l100/same-sky-cms-16093-078l100.step) | Exact manufacturer model | PASS | [Same Sky model ZIP](https://3dcadfiles.3dexchange.net/step_ap203/205/8076781/Same_Sky_CMS-16093-078L100.zip) |
| J1/J3 — JST B2B-PH-K-S | [jst-b2b-ph-k-s.step](../mechanical/components/jst-b2b-ph-k-s/jst-b2b-ph-k-s.step) | Generic exact PH 2-position / 2.00 mm body | PASS | [KiCad JST PH STEP](https://raw.githubusercontent.com/KiCad/kicad-packages3D/master/Connector_JST.3dshapes/JST_PH_B2B-PH-K_1x02_P2.00mm_Vertical.step) |
| J2 — JST BM02B-SRSS-TB(LF)(SN) | [jst-bm02b-srss-tb.step](../mechanical/components/jst-bm02b-srss-tb/jst-bm02b-srss-tb.step) | Exact-ID library model; verify plating/termination option | PASS | [KiCad JST SH STEP](https://gitlab.com/kicad/libraries/kicad-packages3D/-/raw/master/Connector_JST.3dshapes/JST_SH_BM02B-SRSS-TB_1x02-1MP_P1.00mm_Vertical.step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) |
| SW2 — C&K JS202011AQN | [jst-js202011aqn.step](../mechanical/components/jst-js202011aqn/jst-js202011aqn.step) | Exact-ID library model | PASS | [KiCad JS202011AQN STEP](https://raw.githubusercontent.com/KiCad/kicad-packages3D/master/Button_Switch_THT.3dshapes/SW_CuK_JS202011AQN_DPDT_Angled.step) |
| C1/C3 — Murata GCM188R71H104KA57J | [generic-c-0603-1608metric.step](../mechanical/components/murata-gcm188r71h104ka57j/generic-c-0603-1608metric.step) | Generic exact 0603 / 1608 metric package | PASS | [KiCad C0603 STEP](https://raw.githubusercontent.com/KiCad/kicad-packages3D/master/Capacitor_SMD.3dshapes/C_0603_1608Metric.step) |
| C2 — YAGEO CC0805KRX5R8BB106 | [generic-c-0805-2012metric.step](../mechanical/components/yageo-cc0805krx5r8bb106/generic-c-0805-2012metric.step) | Generic exact 0805 / 2012 metric package | PASS | [KiCad C0805 STEP](https://raw.githubusercontent.com/KiCad/kicad-packages3D/master/Capacitor_SMD.3dshapes/C_0805_2012Metric.step) |
| R1/R2/R3/R4/R5/R6/R7/R8 — YAGEO SMD resistors | [generic-r-0603-1608metric.step](../mechanical/components/yageo-rc0603fr/generic-r-0603-1608metric.step) | Generic exact 0603 / 1608 metric package | PASS | [KiCad R0603 STEP](https://raw.githubusercontent.com/KiCad/kicad-packages3D/master/Resistor_SMD.3dshapes/R_0603_1608Metric.step) |
| LED1/LED2 — Kingbright APGF0607G32B33R23-05 | [kingbright-apgf0607g32b33r23-05.step](../mechanical/components/kingbright-apgf0607g32b33r23-05/kingbright-apgf0607g32b33r23-05.step) | Exact manufacturer family model; suffix geometry must be confirmed | PASS | [Kingbright official STEP](https://www.kingbrightusa.com/images/catalog/3D/STEP/APGF0607.STEP) and [product page](https://www.kingbrightusa.com/product.asp?catalog_name=LED&product_id=APGF0607G32B33R23-05) |
| Q1 — AO3400A | [generic-sot-23.step](../mechanical/components/ao3400a/generic-sot-23.step) | Generic exact SOT-23-3 package | PASS | [KiCad SOT-23 STEP](https://raw.githubusercontent.com/KiCad/kicad-packages3D/master/Package_TO_SOT_SMD.3dshapes/SOT-23.step) |
| D1 — NSVR0320MW2T1G | [generic-d-sod-323.step](../mechanical/components/onsemi-nsvr0320mw2t1g/generic-d-sod-323.step) | Generic exact SOD-323 package | PASS | [KiCad SOD-323 STEP](https://raw.githubusercontent.com/KiCad/kicad-packages3D/master/Diode_SMD.3dshapes/D_SOD-323.step) |

## Unresolved or non-purchasable entries

| Ref / component | Model path | Status and reason |
|---|---|---|
| BAT1 — NOVA 603450, 1100 mAh | — | UNRESOLVED. No exact 603450 STEP or defensible generic exact-ID STEP was found from the [Robu listing](https://robu.in/product/nova-603450-1100mah-3-7v-micro-lipo-battery-pack/) or wider search. The generic 603450 PDF in the datasheet folder is documentation only. |
| M1 — Robu flat 1027 motor | — | UNRESOLVED. The [Robu URL](https://robu.in/product/flat-1027-mobile-phone-vibration-motor/) currently renders Flat 1034 (10 mm × 3.4 mm), not a verified 1027, and exposes no CAD. An exact LCM1027A2445F ECAD listing was found, but no downloadable STEP was obtained, so a different motor model was not substituted. |
| SW1 — C&K PTS841GKSMTR-LFS | — | UNRESOLVED. The [DigiKey CAD page](https://www.digikey.in/en/models/10445315) and manufacturer/aggregator pages did not yield a direct exact STEP. The visually similar PTS645 model was deliberately not used. |
| M1-HARNESS — pre-terminated JST-PH cable | — | UNRESOLVED. No cable-assembly STEP was found for the [Sunrom item/category](https://www.sunrom.com/c/jst-ph-20mm); the J3 connector model above is not a harness substitute. |
| 7Semi MAX17048 breakout | — | UNRESOLVED board-level model. The [IoTCart listing](https://iotcart.in/product/max17048-li-poly-li-ion-fuel-gauge-breakout-board-mini-7semi) exposes no verified 3D download. The bare MAX17048 package model above is not a breakout-board model. |
| Hubtronics BMI270 breakout / ES-12135 | — | UNRESOLVED board-level model. A 7Semi BMI270-board STEP was found, but it is a different manufacturer/board and was not copied as an identity-mismatched substitute. |
| Temporary motor test setup | — | UNRESOLVED; same Robu motor source as M1. |
| TP3/TP4 test pads | N/A | PCB features, not purchased components. |
| Custom shutter, loop, shell, antenna mount, LED ports, battery pocket, speaker cavity/grille, magnets and fasteners | N/A | Custom mechanical items, not components represented by this sourced-part manifest. |

## Rejected CAD candidates

These were checked as possible generic substitutes and intentionally not copied into the repository because their identity or envelope did not match the BOM component:

| Component | Candidate | Why rejected |
|---|---|---|
| BAT1 — 603450 LiPo | Marathon battery STEP | Published bounding box is 48.70 × 45.15 × 82.48 mm, not the 603450 6 × 34 × 50 mm envelope. |
| BAT1 — 603450 LiPo | TinyCircuits ASR00012 / 803040 CAD archive | 40 × 30 × 8 mm and no STEP/STP file; not an exact 603450 substitute. |
| M1 — flat 1027 motor | Precision Microdrives 310-101 STEP | Public STEP is for a 10 × 3.4 mm motor; target class is 10 × 2.7 mm. |
| M1 — flat 1027 motor | Marathon vibration-motor STEP | Published bounding box is 150 × 169 × 295 mm; not a coin-motor envelope. |
| SW1 — PTS841 | C&K PTS645 STEP | Different switch family and geometry; not an exact 3.6 × 3.5 × 1.25 mm PTS841 model. |

The local `mechanical/components/` directory therefore contains 14 source STEP files for the components that could be sourced and validated without inventing geometry. The unresolved entries are part of the manifest so they cannot be mistaken for completed coverage.

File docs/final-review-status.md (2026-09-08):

# Final review in progress

Acceptance gates: two-layer carrier; retained exact XIAO Sense, MAX98357A, PH battery and SH speaker connectors; top-side components; 28 x 70 mm R2 carrier, four M2 holes; PA12 enclosure with integrated breakaway-cord attachment. No manufacturing release until electrical, mechanical and export reviews pass.

Fresh initial checks: ERC passes (41 advice), DRC 33 missing connections and 30 warnings, DFM passes. No copper. Auto-routing is withheld pending mechanical allocation and placement acceptance.

J1 moved from (94,120) to (100,129) KiCad mm, rotation 180, to move through-hole tails outside the battery tray (CAD Y +/-22 mm). Source comment reconciled; board backup saved by applyPcbPlacement. Screenshot reviewed: no footprint-envelope collision at new location; speaker seat/mated connector height still needs checking. This is a candidate, not accepted final placement.

Updated review: silkscreen clearance/overlap warnings and R1 pad-rotation mismatch are cleared by fresh DRC. Remaining U1/U2 library mismatch warnings are intentional board-only graphic-layer changes, documented in silkscreen-warning-disposition.json with comparison of pad positions, sizes, shapes, nets and drills against the pre-edit board. Do not regenerate the board to remove these exceptions.

Rear depth increased from 9 to 13 mm. At floor Z=-11, the reserved 6 mm cell envelope reaches Z=-3.85; assembled tails must not extend below Z=-2.5, leaving 1.35 mm static vertical clearance. This is conditional on restrained battery position and verified assembled tail projection, not proof of supplier swelling allowance. Cloud revision rev-11f47cda12a3dc63c7106330bc945c2d2428569f6d48420d5ed7f90a180c18e1 passed cavity/floor checks, four single nonempty valid solids, selected part-pair interference checks, and all through-hole-tail/tray interference checks. Exploded snapshot reviewed; occlusion still limits visual fit inspection.

J2 MP1/MP2 are explicitly optional isolated mechanical-tab nets in its existing wrapper, each on a separate pad. They are not functional signal nets and must remain isolated; no invented connection or copper route between them is authorized.

Remaining gates: speaker/J1 mated height; exact Sense microphone/antenna/USB geometry; battery protected maximum envelope/current limits and retention; switch actuator access; fasteners and print qualification; routing and post-route review. Supplier and physical measurements cannot be replaced with successful CAD builds. Auto-layout remains withheld under the requested mechanical-first gate. Old separate STEP exports are stale after the depth change.

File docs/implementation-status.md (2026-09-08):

# Implementation checkpoint — partial, not release-ready

Confirmed product: no camera, retain speaker/playback, microSD recording and
eventual BLE sync to Android/iPhone. No completed BLE receiver is claimed.

Implemented:
- Correct XIAO ESP32S3 target in manifest, PlatformIO and IDE selection.
- Offline recording firmware; removed Wi-Fi startup and fake uploader queue.
- Correct WAV RIFF/data sizes; sample-count-based 15-second chunks.
- Bounded acquisition queue, separate SD writer, debounced press-to-toggle control.
- NVS-reserved file IDs, checked writes, .part finalization and boot recovery;
  malformed short files retained as .bad. No automatic recording deletion.
- Full-storage/open/write/queue faults stop recording; amplifier remains disabled.
- Camera opening removed from cloud-built enclosure, speaker grille retained.

Verification: firmware compiled/linked for seeed_xiao_esp32s3 using managed
Espressif32 55.3.38 / Arduino 3.3.8. The build tool normalizes platformio.ini;
it did not use the initially requested 6.10.0 pin. Native C++ WAV/CRC tests pass
with -Wall -Wextra -Werror. No device recording test was performed.
Mechanical revision rev-85f58fc1b3e33b115722a790ac3d0f96a54bfad073769a41b468977a083f3704
uses current source/parameters/PCB context: four shapes, 32 x 76 x 24 mm assembly.
Only inspectable solids/bounds verified, not hardware fit or direct visual review.
Legacy camera parameters are inert; prior manifest geometry assumptions remain
provisional and must be reconciled before release.

Unfinished: BLE service, authenticated pairing, resumable transfer, durable
acknowledgements, Android/iPhone app, playback implementation, battery sensing,
low-battery behavior, exact component selection, PCB routing/DFM release, mic
metrology and control/connector fit. No fabrication artifacts exported.

Firmware validation still needed: SD CS=21 against exact Sense revision, microphone
sample scaling, missing card, removal mid-write, queue overflow, power cuts during
NVS update/write/header/rename, button timing around chunk rollover, full storage,
long-duration dropout detection. FAT rename/flush are NOT guaranteed power-fail
atomic; repair is best-effort and physical fault-injection is required. DMA loss
inside the driver is not yet tracked; queue fault detection alone is insufficient.
Recovered odd trailing bytes are excluded from the WAV data length, not erased.

PCB preserved unchanged this pass; earlier 33 unrouted/30-warning result remains
the baseline, not a new validation. Historical mechanical README/PCB review
revision IDs describe earlier checkpoints; this document records the current one.

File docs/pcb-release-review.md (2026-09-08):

# PCB/enclosure reconciliation — release blocked

Requirements: 32 x 76 mm enclosure exterior, rectangular elongated carrier,
two copper layers, 1.62 mm current PCB thickness, all components on front,
no underside components over the LiPo tray. Initial 27 x 67 mm target, now
28 x 70 mm chamfered board centered
at KiCad (100,100), CAD X=KiCad X-100, CAD Y=100-KiCad Y.
Mount centers CAD (+/-12,+/-32), 2.2 mm NPTH, subject to edge/fastener review.
Fabrication target: ordinary FR4 two-layer prototype, no order approval implied.

Initial evidence: six footprints, no outline, no copper; original fingerprint
8005c5678a30f30112cf4cf8ed2af8cf5f10719aa639c57425e5a48e7c8ea25c.
All existing locks are inherited draft state, not evidence of placement acceptance.

Electrical findings: I2S BCLK currently uses D8/GPIO7, also microSD SCK;
move BCLK to unused D3/GPIO4. EN is a reset INPUT, not amplifier GPIO control;
disconnect amplifier shutdown from module EN. Resolve low-battery SD_MODE
absolute maximum and power-off behavior before release. Speaker, cell,
connectors, switches and antenna envelopes must be selected/verified.
XIAO record peak camera current is ~366 mA before amplifier load: a 0.3 A
slide switch is NOT approved as a direct whole-device battery disconnect.

Mechanical findings: camera/mic coordinates in enclosure are placeholders,
USB mating plane is unverified, module wrapper says approximately 15 mm stack
while enclosure assumes 10 mm. Do not claim exact fit until reconciled.
Source: Seeed filesystem wiki confirms GPIO7/8/9 used by SD SPI, but contradicts
itself on CS (GPIO3 vs GPIO21); resolve from exact board revision schematic.

Acceptance: source build/netlist, electrical review, actual outline/holes,
whole-board placement review, route/return-path review, fresh ERC/DRC/PDK DFM,
STEP fit/interference review, exact BOM and same-revision verified fabrication
exports. Fit, skin temperature, RF, audio and battery safety require prototype tests.

## Current implementation and checks

Added J1 battery and J2 speaker JST B2B-PH-K-S connectors (pin 1 positive,
pin 2 negative), SW1 PTS645SM43SMTR92 LFS record button, SW2 JS202011AQN
standby switch, R3 2 kohm SD_MODE series resistor, four M2 2.2 mm NPTHs.
R3 is grounded in MAX98357 datasheet chunk 0042, which recommends ~2 kohm
when the 3.3 V control supply can exceed amplifier VDD. D3/GPIO4 is now
BCLK; D4/GPIO5 drives AMP_ENABLE through R3. The module EN has its own net.
SW2 grounds MCU_EN and AMP_SD in standby. Battery and charger remain connected;
this is NOT the true battery isolation circuit required for final release.

Latest source build passes (15 components); netlist and repeated board screenshots
inspected. Current physical outline is 28 x 70 mm with 1.2 mm corner chamfers,
center (100,100), four mounting holes at (88,68), (112,68), (88,132), (112,132).
The holes match the existing enclosure XY standoff centers. Actual drill-to-side
distance is 0.9 mm; 4.3 mm courtyard rings extend 0.15 mm beyond the board and
are NOT drilled holes. Fastener bearing strength remains unqualified.

Latest checks 2026-09-07T12:16:24Z:
- ERC: pass, 0 errors/warnings, 41 style advice.
- DRC: FAIL, 33 unconnected errors, 30 warnings (silk and R1 library mismatch).
- PDK DFM: 10 rules passed, 5 skipped, no findings. This does not qualify an
  unrouted board for fabrication. `canOrder=false`.
- No routing or fabrication exports performed. No source-only success is a fit pass.

Placement metadata helper rejected positions because it could not resolve footprints
and generated extraneous inferred IDs. Nothing from that rejected operation was
applied. Exact runtime IDs and actual board coordinates were instead persisted with
a focused source patch, which passed evaluation. Regeneration behavior still requires
comparison; retain the current physical board rather than regenerating as a refresh.

## Remaining blockers (do not order)

- Exact module stack/lens/mic metrology is unavailable; the existing 13 mm front Z
  is NOT established as sufficient for the approximate 15 mm assembly height.
- SW1 is now top-actuated at CAD (-1,+6), but enclosure still has a SIDE button
  opening. It requires a qualified front plunger/opening or an exact side switch.
- J2 through-hole tails project into the nominal under-board cell region. Move the
  connector or change to a verified low-profile SMT mating system; no solder point
  may contact the cell. J1 and the speaker retaining ring also need a 3D fit review.
- Selected PH header supports 0.8–1.6 mm board thickness per record; current board
  says 1.62 mm. Resolve nominal stackup and connector tolerance before release.
- Cell and speaker MPNs unresolved. Equal J1/J2 housings permit dangerous cross-mating;
  use different keyed systems or a captive assembly with documented safeguards.
- U1 USB graphic intentionally faces the top, but actual mating face is not verified
  against the shell opening. SW2 side actuator reach is similarly unverified.
- Need antenna/coax keepout, hard power isolation, test points, supply/current budget,
  exact passive ratings/MPNs, assembly access, silk cleanup and routed return paths.
- Enclosure revision ec844702 remains the earlier concept; it was NOT rebuilt or
  validated against this new PCB context. Its old no-outline statements are historical.

Original board preserved at `pcb/backups/pre-enclosure-fit.kicad_pcb`; this backup is
the six-component UNROUTED input, not a manufacturing-ready recovery image.

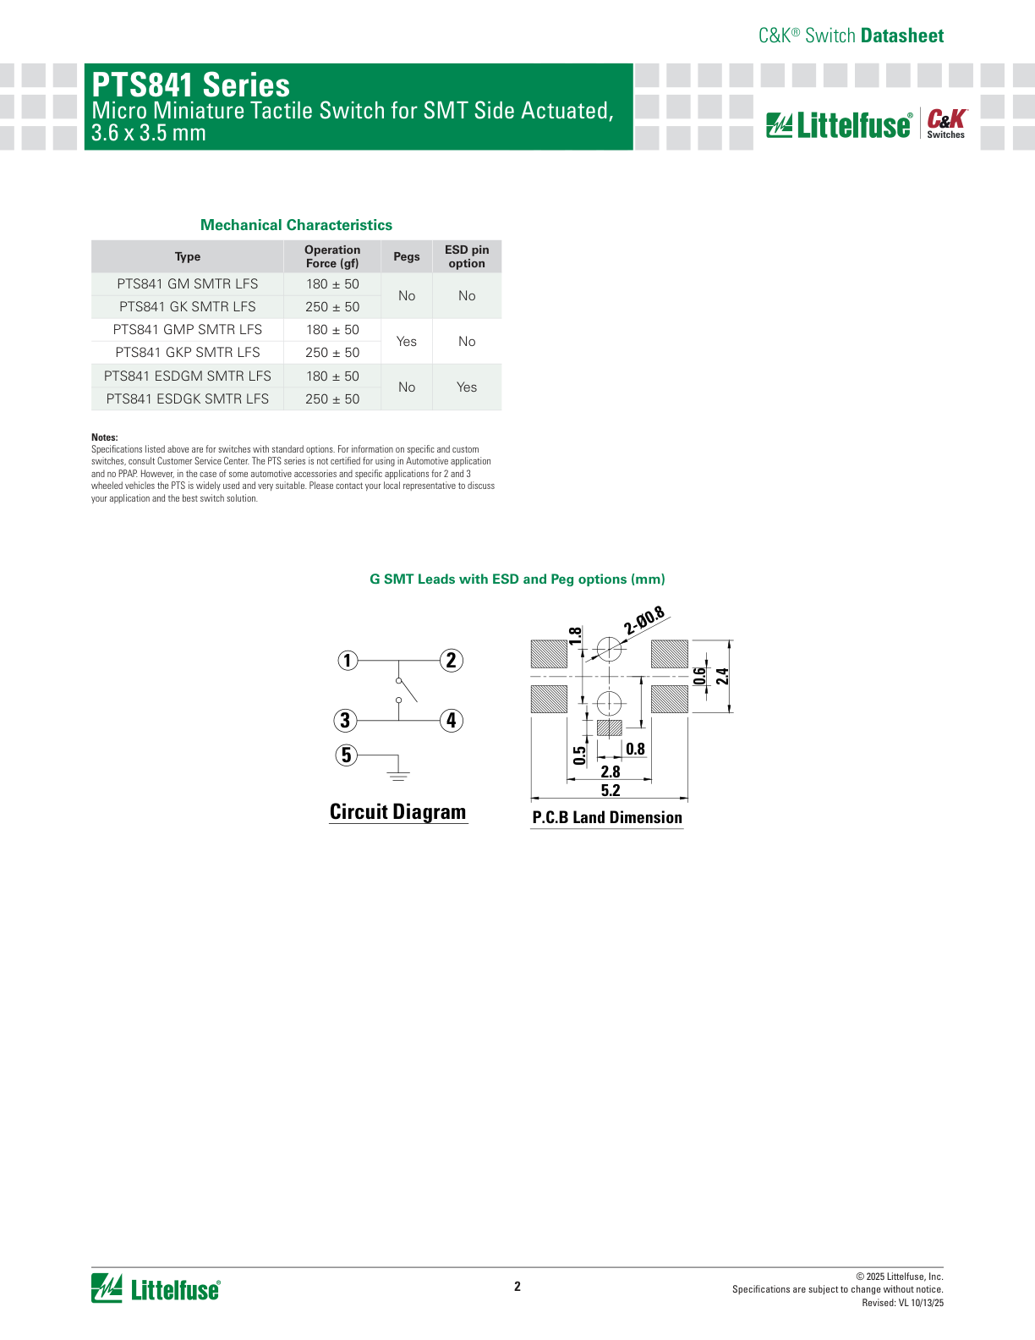
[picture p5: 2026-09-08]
docs/datasheets/pts841-page-1.png

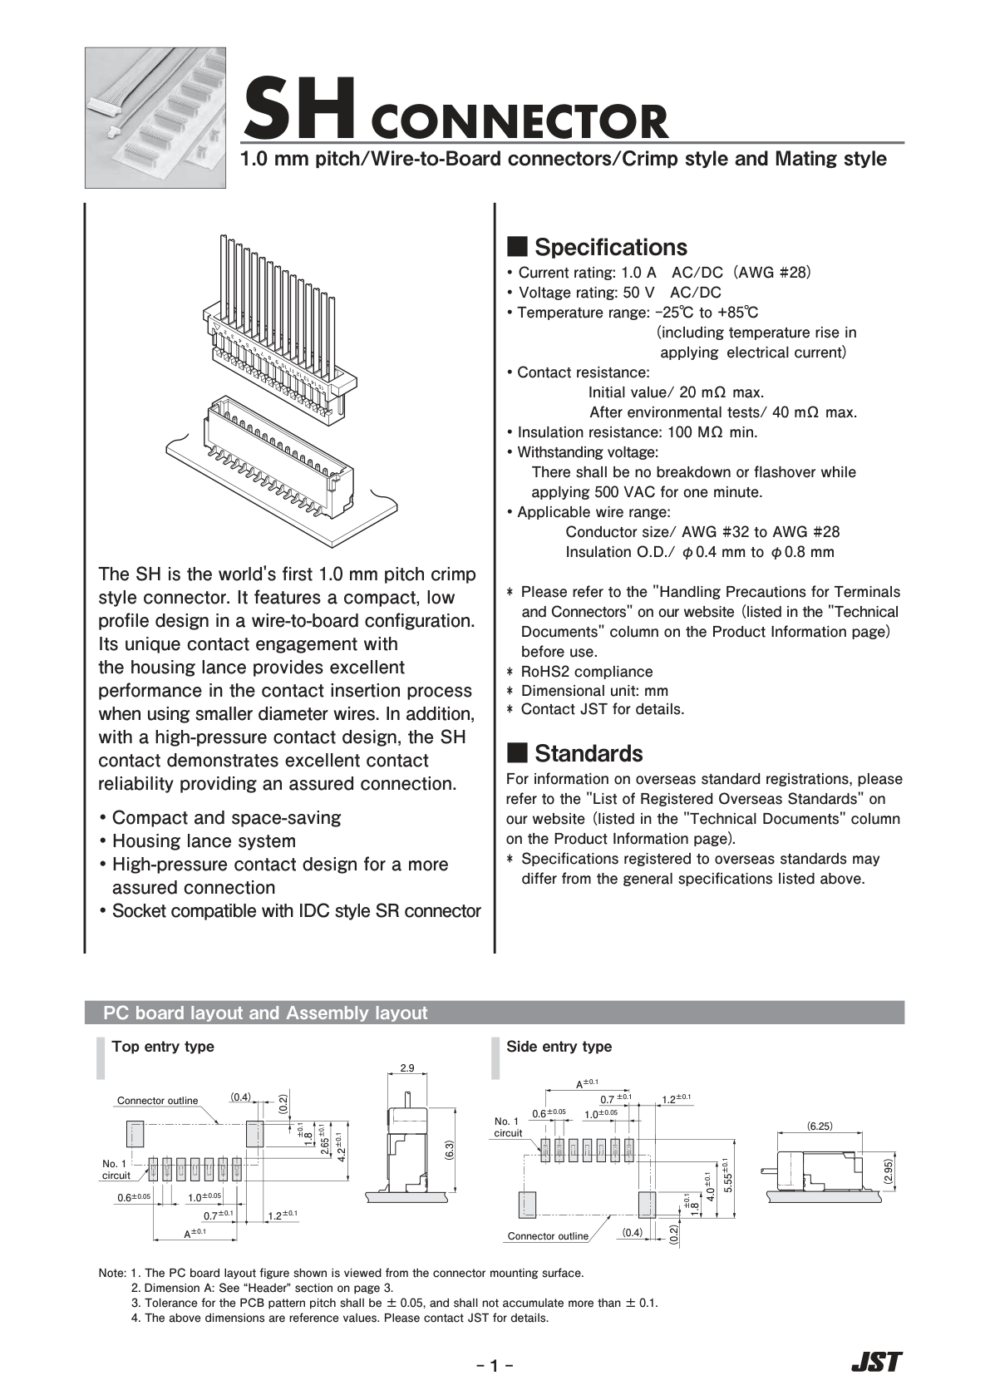
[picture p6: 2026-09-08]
docs/datasheets/jst-page-0.png

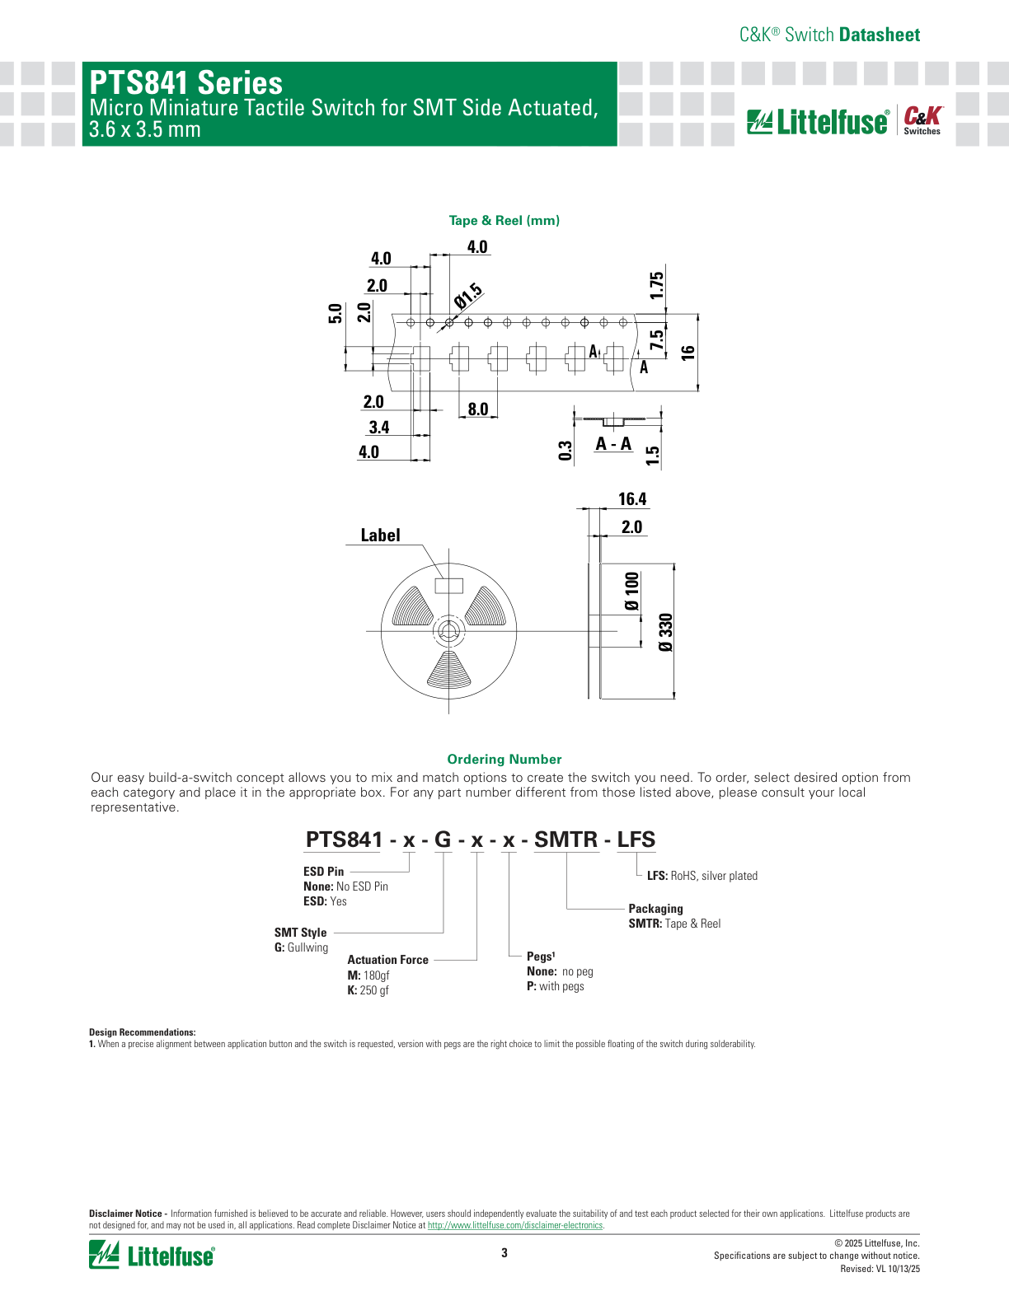
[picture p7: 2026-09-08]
docs/datasheets/pts841-page-2.png

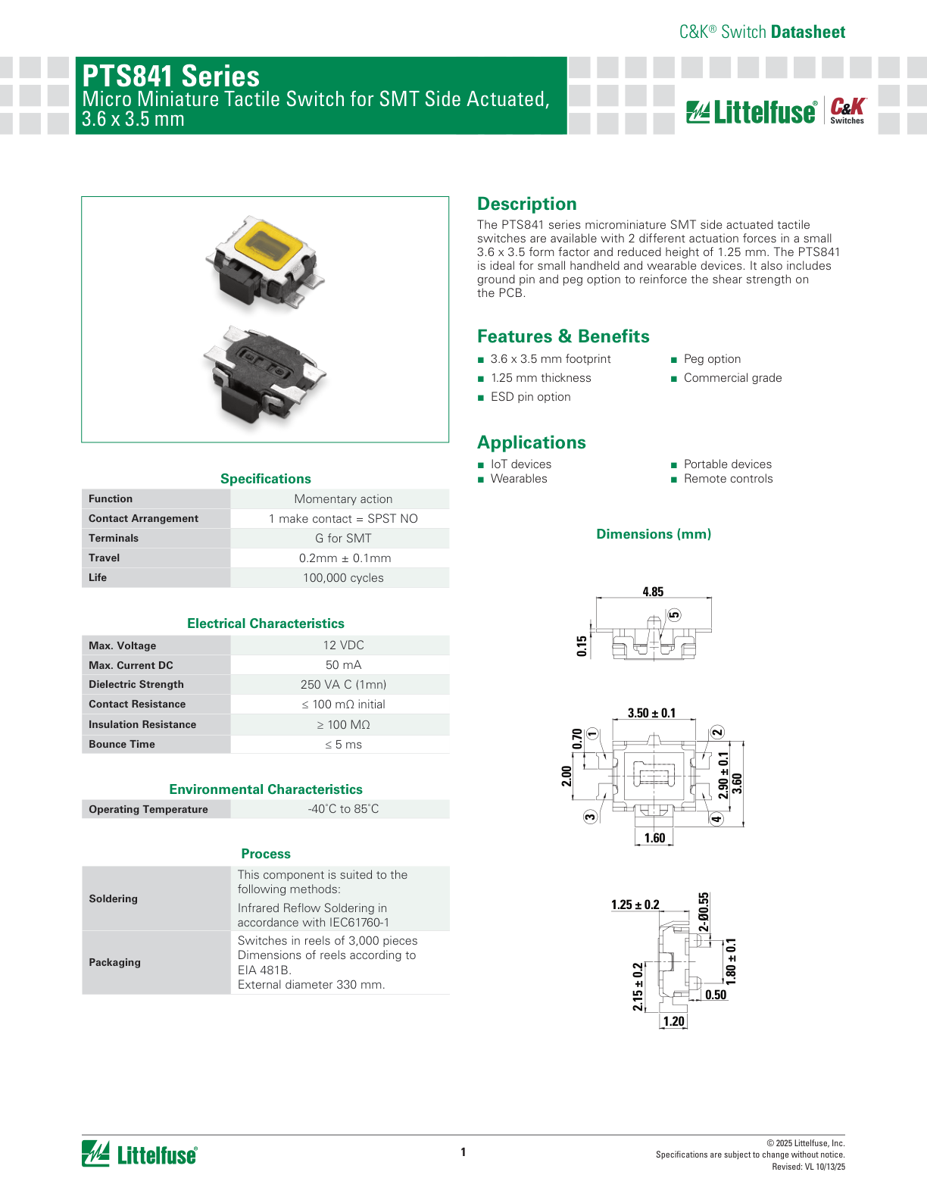
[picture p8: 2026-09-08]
docs/datasheets/pts841-page-0.png

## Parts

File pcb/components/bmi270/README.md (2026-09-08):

# BMI270 private package

Grounding: retained `docs/datasheets/bmi270.pdf`, SHA256
`f68ce3c74f011a80bbe4b0279c4abe9609a71a5dcda75a951381d77112e005fb`,
BST-BMI270-DS000-08, pp135 (pins),137 (I2C),143 (package),145 (lands).
No installable Embedr record found. Upstream asset URLs did not resolve;
local symbol and lands authored from the manufacturer drawing.

14 lands, 0.5 mm pitch, 0.475 × 0.25 mm side pads; inner pad edges
0.925 mm from vertical centreline and 0.675 mm from horizontal centreline.
Pin 1 upper left; 1–4 down left, 5–7 across bottom, 8–11 up right,
12–14 across top right to left. No exposed pad. Courtyard is a design allowance.
Mask/paste use KiCad defaults and need fabrication-profile review.

3.3 V VDD/VDDIO; separate 100 nF bypasses. SDO grounded (0x68), CSB high.
Unused auxiliary and interrupt pins NC, not grounded. Firmware must load Bosch
configuration data and set sensor-to-product axis mapping. Polling does not
provide interrupt-based motion wake. Physical layout is not validated yet.

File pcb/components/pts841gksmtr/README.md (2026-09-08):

# PTS841GKSMTR LFS — private exact package

Source: uploaded Littelfuse/C&K PTS841 datasheet, page 2,
`ds_6387b39722da309d0fd7`, retained at `docs/datasheets/pts841.pdf`.
Top view: upper left/right 1/2, lower left/right 3/4; 1–2 common,
3–4 common; normally open between groups. Actuator faces +Y.

Land pattern: 5.2 mm outer width, 2.8 mm inner gap => 1.2 mm pad
width and X centers ±2.0 mm. 2.4 mm outer height, 0.6 mm row gap
=> 0.9 mm pad height and Y centers ±0.75 mm. GK has neither pegs
nor ESD terminal: omit optional Ø0.8 holes and terminal 5.
Body is 3.5 mm wide; body depth 2.9 mm with actuator extension
0.7 mm. Overall nominal depth 3.6 mm; height 1.25 ±0.2 mm.

Not a shared-library publication. Requires fixture build and rendered
footprint/symbol review before installation on the pendant board.

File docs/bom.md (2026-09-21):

# Base-XIAO recorder with 5x5 RGB matrix — procurement BOM

Generated from `pcb/bom.csv`; electrical source refs may differ from physical KiCad refs.
Purchase links were confirmed in stock by the user; no numerical inventory
or current prices were provided. Availability remains time-sensitive. See [validation and GPIO map](current-design.md).

## Carrier PCB components

| Qty | Source refs | MPN | Value / function | Existing sourcing link |
|---:|---|---|---|---|
| 6 | C1 / C3 / C4 / C5 / C9 / C10 | GCM188R71H104KA57J | 100nF 50V X7R | [Purchase](https://www.digikey.in/en/products/detail/murata-electronics/GCM188R71H104KA57J/4380305) |
| 5 | C2 / C7 / C8 / C11 / C12 | CC0805KRX5R8BB106 | 10uF 25V X5R | [Purchase](https://www.mouser.in/en/ProductDetail/YAGEO/CC0805KRX5R8BB106?qs=CNuWj9FTWYDQ%252BJODP2bXGA%3D%3D) |
| 1 | D1 | NSVR0320MW2T1G | NSVR0320 | [Purchase](https://in.element14.com/on-semiconductor/nsvr0320mw2t1g/schottky-diode-20v-sod-323/dp/2533249) |
| 2 | J1 / J3 | B2B-PH-K-S | JST_PH_B2B-PH-K_1x02_P2.00mm_Vertical | [Purchase](https://www.digikey.in/en/products/detail/jst-sales-america-inc/B2B-PH-K-S/926611) |
| 1 | J4 | 104031-0811 | Molex 1.42 mm push-pull microSD socket with detect | [Purchase](https://www.mouser.in/en/ProductDetail/Molex/104031-0811?qs=udsGRKD4nA3Tvy7wqky%252BuA%3D%3D) |
| 1 | MK1 | IM69D130V01XTSA1 | IM69D130 | [Purchase](https://in.element14.com/infineon/im69d130v01xtsa1/mems-microphone-3-6v-module/dp/2986420) |
| 1 | Q1 | AO3400A | SOT-23 | [Purchase](https://www.digikey.in/en/products/detail/alpha-omega-semiconductor-inc/AO3400A/1855772) |
| 5 | R1 / R8 / R23 / R26 / R27 | RC0603FR-07100KL | 100k 100mW | [Purchase](https://www.digikey.in/en/products/detail/yageo/RC0603FR-07100KL/726889) |
| 2 | R4 / R5 | RC0603FR-074K7L | 4.7k 100mW | [Purchase](https://www.digikey.in/en/products/detail/yageo/RC0603FR-074K7L/727212) |
| 1 | R7 | RC0603FR-07100RL | 100 100mW | [Purchase](https://www.digikey.in/en/products/detail/yageo/RC0603FR-07100RL/726888) |
| 2 | R16 / R17 | RC0603FR-0733RL | 33 100mW | [Purchase](https://in.element14.com/yageo/rc0603fr-0733rl/res-33r-1-0-1w-0603-thick-film/dp/9238301) |
| 5 | R18 / R19 / R20 / R21 / R22 | RC0603FR-0747KL | 47k 100mW | [Purchase](https://in.element14.com/yageo/rc0603fr-0747kl/res-47k-1-0-1w-0603-thick-film/dp/9238689) |
| 1 | SW1 | PTS841GKSMTR LFS | PTS841GK | [Purchase](https://www.digikey.com/en/products/detail/c-k/PTS841GKSMTR-LFS/10445315) |
| 1 | SW2 | JS202011AQN | SW_CK_JS202011AQN_DPDT_Angled | [Purchase](https://www.digikey.in/en/products/detail/c-k/JS202011AQN/1640096) |
| 1 | U1 | 113991114 | XIAO | [Purchase](https://www.seeedstudio.com/XIAO-ESP32S3-p-5627.html) |
| 1 | U3 | MAX17048G+T10 | kicad_footprint | [Purchase](https://www.digikey.in/en/products/detail/analog-devices-inc-maxim-integrated/MAX17048G-T10/3758921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) |
| 1 | U4 | BMI270 | BMI270 | [Purchase](https://www.digikey.in/en/products/detail/bosch-sensortec/BMI270/9974486) |
| 1 | U6 | AP2112K-3.3TRG1 | AP2112K_3V3 | [Purchase](https://in.element14.com/diodes-inc/ap2112k-3-3trg1/ldo-fixed-3-3v-0-6a-sot-25-85deg/dp/3257429) |
| 25 | LED1–LED25 | WS2812C-2020-V1 | 2.0 mm addressable RGB, 5 mA/channel | [Purchase](https://www.lcsc.com/product-detail/C2976072.html) |
| 25 | C15–C39 | GRM155R71C104KA88D | 100 nF 16 V X7R 0402, one per pixel | [Purchase](https://in.element14.com/murata/grm155r71c104ka88d/cap-mlcc-0-1uf-x7r-16v-0402/dp/4326785) |
| 1 | U5 | TPS61023DRLR | 5 V synchronous boost converter | [Purchase](https://www.mouser.in/en/ProductDetail/Texas-Instruments/TPS61023DRLR?qs=BJlw7L4Cy7%2FfEnwYuWeGOg%3D%3D) |
| 1 | U7 | TPS22918DBVR | 2 A load switch, switched LED rail | [Purchase](https://www.mouser.in/en/ProductDetail/Texas-Instruments/TPS22918DBVR?qs=f4l5qYp%2Fy%252B5F7w5ZAgmi7A%3D%3D) |
| 1 | L1 | XEL4030-102MEC | 1 uH shielded power inductor | [Purchase](https://www.mouser.in/en/ProductDetail/Coilcraft/XEL4030-102MEC?qs=chTDxNqvsynxP6L4IWrGOQ%3D%3D) |
| 2 | C13 / C14 | GRM21BR61A226ME44L | 22 uF 10 V X5R 0805 | [Purchase](https://www.mouser.in/en/ProductDetail/Murata-Electronics/GRM21BR61A226ME44L?qs=eeBpzGFlv%2B8tSfxib2AMhw%3D%3D) |
| 1 | R25 | RC0603FR-07732KL | 732k 1% boost feedback | [Purchase](https://www.digikey.com/en/products/detail/yageo/RC0603FR-07732KL/727376) |
| 1 | R28 | RC0603FR-07470RL | 470 ohm LED data series resistor | [Purchase](https://www.digikey.com/en/products/detail/yageo/RC0603FR-07470RL/727256) |
| 1 | C40 | GRM1555C1E102JA01D | 1 nF 25 V C0G 0402, TPS22918 rise-time control | [Purchase](https://www.mouser.in/en/ProductDetail/Murata-Electronics/GRM1555C1E102JA01D?qs=y02iAgv9n62vwTD5aUQSxQ%3D%3D) |

## Off-board / assembly procurement

| Qty | Item | Requirement / source status |
|---:|---|---|
| 1 | BAT1 Adafruit 1578 / PKCELL LP-503035 family, protected 1S LiPo | 3.7 V nominal, 500 mAh, 4.2 V CC/CV, 1C / 500 mA maximum continuous discharge, PCM and two-wire JST-PH lead. Conservative CAD pack envelope 30.1 x 36.0 x 5.1 mm; tray reserves 30.1 x 36.0 x 6.1 mm including 1 mm expansion allowance. No NTC. [Adafruit product 1578](https://www.adafruit.com/product/1578) (USD 7.95 and in stock when selected); [manufacturer datasheet](https://cdn-shop.adafruit.com/product-files/1578/Datasheet.pdf); [India distributor family listing](https://www.fabtolab.com/lithium-polmer-1s-battery) (exact 1578 option stock/price must be confirmed). **Selected for tray design, not yet purchase-approved.** |
| 1 | M1 exact vibration motor TBD | Old Robu 1027 URL served 1034. **Replacement exact link with start/stall current and dimensions required.** Must tolerate regulated 3.3 V. |
| 1 | microSD card, exact MPN/capacity TBD | Prefer traceable high-endurance 16–32 GB FAT32 for prototype; **link needed**. Qualify write latency and peak/standby current. |
| 1 set | Battery and motor harnesses | J1/J3 PH 2 mm; confirm polarity, wire length, and connector orientation. Motor PH pigtail has prior Sunrom link. |
| 1 set | Microphone acoustic gasket / dust mesh | **Supplier links needed**, thickness and acoustic impedance TBD after port design. |
| 1 | XIAO-compatible 2.4 GHz antenna | Confirm supplied with base SKU; otherwise exact antenna link/drawing needed. |

## Changes and purchasing cautions

- Selected BAT1 Adafruit 1578 as the active tray basis. Adafruit documents
  overcharge, over-discharge and short-circuit protection; the supplier drawing
  shows a 1S PCM. Exact overcurrent threshold remains a procurement gate.
- Adafruit states that this pack has no thermistor. Existing two-pin J1 supports
  VBAT and GND only, so it cannot monitor an NTC. Confirm charger compatibility,
  delivered connector polarity, and current before energizing the assembly.
- Adafruit lists 29 x 36 x 4.75 mm while its attached pack drawing shows
  30 +/-0.1 x 35 +/-0.1 x 5 +/-0.1 mm. The mechanical design uses the
  conservative union rather than treating either nominal description as exact.
- BAT1 documentation: indexed datasheet `ds_dcee32f4e0c985211bc8`. UN38.3/MSDS applicability, India shipping,
  delivered-pack metrology and load/thermal testing remain required.
- Resistor purchasing links are saved in the carrier table and structured BOM.
- AP2112K-3.3TRG1 sourcing is saved in Zen and the structured BOM.
- Additional 100nF/10uF/100k parts reuse existing MPN links; no new passive selection needed for those.
- H1–H4 and TP3/TP4 are PCB features, not purchased components. Mounting hardware remains mechanical-design TBD.
- Flyback D1 cathode is MOTOR_3V3, NOT VBAT.
- J1/J3 through-hole PH headers and SW2 remain provisional thickness risks.
- Speaker, MAX98357A amplifier, speaker connector, gain/shutdown network, and speaker mechanics are removed.
- A 5x5 WS2812C-2020-V1 matrix is the central visual interface. Its 5 V rail is firmware-enabled and must use a brightness/current budget; do not combine full-white output with motor start/stall load.
- TPS22918 U7 is now present between BOOST_5V and LED_5V. C40 controls rise time and QOD directly discharges LED_5V when disabled; bench inrush and thermal validation remain mandatory.
- Microphone is frozen as IM69D130V01XTSA1. J4 is frozen as active Molex 104031-0811; its manufacturer drawing and KiCad footprint establish the land pattern, but card-access and component-envelope clearance still require revised placement review.

## Confirmed product decisions

- Retain JS202011AQN and use one pole for standby/reset; the second pole remains intentionally unconnected.
- Share one GPIO between TPS61023 EN and TPS22918 ON.
- Charge the protected Adafruit 1578 through the XIAO ESP32S3 onboard battery charger/USB path, subject to polarity and bench compatibility verification.
- Limit the LED rail design target to 100 mA; full-matrix white is prohibited.
- Freeze IM69D130V01XTSA1, Molex 104031-0811, and the existing regulated 3.3 V haptic architecture. The exact motor remains a downstream procurement/fit qualification.

## Carrier sourcing
Links were confirmed in stock by the user; no numeric inventory or current prices were provided. Motor, card, and acoustic-material procurement remain open. C40 manufacturer search flags NRND: retain the selected part and review lifecycle before production.

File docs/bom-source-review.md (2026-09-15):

# Superseded reference

Historical content: [archive](archive/pre-bom-finalization/bom-source-review.md). Use [current BOM](bom.md), [LED contract](rgb-matrix.md), and the current Zen source. Historical checks do not release this revision.

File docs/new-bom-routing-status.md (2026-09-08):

# New BOM integration / routing — placement frozen, ready for routing

## Route-readiness revision 220f3ac0

- Closed 28 x 70 mm two-layer outline retained. All 15 footprints are on the
  front, inside by anchor, and locked against accidental routing-time movement.
- M2 NPTH centers moved to X=88.2/111.8, Y=68.5/131.5. Their rendered
  envelopes now fit inside Edge.Cuts; mechanical generator must use the same
  board-derived centers on its next build.
- U2 amplifier moved to (100,96); its 100 nF and 10 uF bypass capacitors and
  SD-mode resistors are grouped locally. J2 speaker connector is immediately
  below the amplifier. R1 is between the XIAO and side record switch.
- SW1 is intentionally edge-actuated at (112,94), rotation 90; its copper pads
  are inside and only the actuator/courtyard crosses the right Edge.Cuts.
  SW2 similarly has an intentional right-edge actuator overhang. U1 remains at
  the top edge for USB access and Sense-board volume.
- J2 mechanical anchors now have distinct MP1/MP2 pad/net attribution. They
  remain electrically isolated from each other and ground. Fresh PDK DFM now
  passes instead of aborting on unattributed copper.
- Primary source build and exact netlist inspection pass. Fresh ERC has zero
  errors/warnings (41 style advice). Fresh DRC has 33 missing-connection errors,
  exactly the expected unrouted state, plus 30 pre-routing silkscreen/library
  warnings. There are zero tracks, vias, or zones.
- Full F.Cu/F.Fab/Edge.Cuts capture was reviewed: no footprint intersection,
  all electrical pads are inboard, and the two intentional right-edge controls
  remain accessible. This is ready to enter routing, not fab-ready.

Routing constraints: retain two layers; preserve all 15 placements; treat the
four NPTH mounting holes as obstacles; use wider copper for VBAT, GND, SPK_P
and SPK_N than logic; keep the BTL speaker pair together and neither output to
ground; route I2S directly without unnecessary vias; retain a continuous ground
return and keep antenna/coax, microphone inlet, USB, and control-access volumes
free. After routing, review F.Cu and B.Cu separately, correct silkscreen, then
rerun ERC/DRC/DFM. The enclosure still requires a fresh board-context rebuild
and physical prototype fit validation; those do not block creating the routing
candidate but do block fabrication release.

## Uploaded-datasheet integration checkpoint

The PTS841 download blocker is resolved. Uploaded document
`ds_6387b39722da309d0fd7` was searched and its complete page 2 and
numbered top-view drawing reviewed. Original PDF retained at
`docs/datasheets/pts841.pdf`.

- Created private PTS841GKSMTR LFS symbol/footprint/package: four numbered
  terminals, common pairs 1–2 and 3–4, no optional pegs or ESD terminal.
- Created private JST BM02B-SRSS-TB(LF)(SN) package from the retained
  upstream KiCad footprint and manufacturer SH drawings. Mechanical tabs
  are unnumbered, electrically floating solder anchors.
- Built both in `pcb/pts841-fixture.zen`; rendered the switch symbol and
  fixture footprints. Integrated SW1 and J2 in the primary source and
  synchronized the board without removing its outline or other parts.
- SW1: (112,94), 90 degrees, actuator toward right edge; pads remain
  inside, nominal actuator projects 0.15 mm beyond edge. Enclosure opening
  remains to be reconciled. J2: (104,102), 0 degrees; pin 1 SPK_P,
  pin 2 SPK_N. Different SH/PH interfaces prevent speaker/battery mating.
- Backup of pre-integration source and physical board/project retained at
  `pcb/backups/pre-pts841-integration/`.
- Primary source build passes (15 components). Fresh ERC: zero errors or
  warnings. Fresh DRC: 33 unconnected-item errors, 30 warnings, five ignored
  checks. No copper was added; routing is NOT completed.
- Latest DFM is unavailable: IPC-2581 rejects unattributed functional
  F.Cu copper. Investigate unnumbered connector mounting tabs/export handling;
  do not assign them a fabricated electrical purpose just to pass a checker.

Remaining before routing acceptance: reconcile larger battery tray, speaker
seat, switch access, connector tails, actual module/microphone/antenna
envelopes and mounting clearances; finish placement review and silkscreen
cleanup; establish routing rules/keepouts, route, review both copper layers,
and rerun checks. Mechanical source and firmware were not changed in this
checkpoint. The historical evidence below predates this integration.

## Authorized scope and retained constraints

User authorized design and PCB placement changes through completed routing.
Use `pendant-parts-selection.md`: protected LP502540 500 mAh cell,
CMS-16093-078L100 wired 8-ohm / 0.7 W speaker, PTS841GKSMTR LFS side
record switch, BM02B-SRSS-TB(LF)(SN) speaker header and documented harnesses.
Retain XIAO 113991115, MAX98357AETE+T and low-current JS202011AQN standby.
Keep two copper layers, front-side assembly, 32 x 76 mm enclosure plan envelope,
and existing 28 x 70 mm board unless mechanical reconciliation requires revision.
Nominal cell voltage is 3.7 V; finished-pack dimensions and permissible load
current remain supplier-dependent. Standby does not provide battery isolation.
Target is a prototype, not an approved manufacturing release.

## Current evidence

- Inspected source, parts shortlist, prior release review, board outline, exact
  placement and pad nets; captured the current board.
- Board fingerprint: `5216797bb57bbe7a78afd967205fa1b0b05646915bb02d6fcb17fc72dd5ab889`.
- 15 footprints, closed outline, 0 tracks, 0 vias, 0 zones; capture reports
  33 unrouted airwires. No new build, ERC, DRC or DFM performed this pass.
- Exact replacement switch and speaker header searches returned no library records.
- JST manufacturer SH PDF retained in `docs/datasheets/jst-sh.pdf`, from
  https://www.jst-mfg.com/product/pdf/eng/eSH.pdf . Privately indexed as
  `ea3071ca5ee5a6069eba534fa39a10f34c9fb742ee42135a69ab4156bfa0f5de`.
- Upstream KiCad BM02B-SRSS-TB footprint downloaded into `docs/datasheets/`
  for comparison only; NOT installed or validated against the drawing yet.
- PTS841 manufacturer PDF direct retrieval/indexing returned HTTP 403.
  Distributor attempts returned HTTP 403 or transport failures. Manufacturer
  text extraction confirms SPST-NO, 50 mA / 12 V, 1.25 mm nominal height,
  0.2 +/-0.1 mm travel; GK has no pegs or ESD pin. Flattened drawing text
  is insufficient to establish exact pad positions and circuit mapping.
- Legacy ckswitches PDF URL redirected to HTML, retained explicitly as
  `pts841-redirect.html`, not usable as a datasheet.

No electrical source, BOM, physical board, enclosure or firmware was changed.
No routing run was submitted. Existing design is preserved, not new-BOM compliant.

## Required next steps

1. Obtain readable PTS841GKSMTR LFS manufacturer drawing PDF (upload is sufficient).
   Inspect its circuit and land pattern images; author and validate an exact private
   package, not a PTS645 or generic-switch footprint substitute.
2. Compare JST drawing with upstream footprint (pad mapping, hold-downs, body,
   pin-one and mating envelope); validate a private connector package.
3. Preserve current source/board revision before replacing SW1 and J2. Sync and
   build, then inspect netlist and synchronize the board without losing its outline.
4. Reconcile side plunger and speaker harness access; move battery connector and
   through-hole standby tails outside the cell envelope or provide verified clearance.
   Resolve PCB 1.62 mm versus PH 1.6 mm nominal stackup. Reconcile battery tray,
   speaker seat and rear depth with drawing tolerances before claiming enclosure fit.
5. Review whole-board geometry and decoupler supply/ground loops, screw envelopes,
   USB access and antenna/coax constraints. Capture corrected placement and run
   fresh checks; disposition all non-routing findings explicitly.
6. Establish power/speaker trace widths and return paths from current and stackup
   assumptions. Request paid routing approval; verify original NPTH/keepout geometry
   survives conversion. Route on F.Cu/B.Cu, inspect both layers and run fresh
   ERC/DRC/DFM. Do not accept only a zero-airwire result.

Battery pulse capability, charge behavior, speaker output ceiling, exact module
stack fit, fastener qualification and thermal/RF/acoustic tests remain release gates.

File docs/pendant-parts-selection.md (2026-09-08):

# Pendant exact-parts selection — prototype shortlist, not fit release

## Basis and decision

Preserve the 32 x 76 mm plan envelope and camera-free front in the current
`mechanical/pendant.py`. Older README camera-bore descriptions are historical.
The existing tray has a 21 x 35 mm cavity; its nominal 20 x 34 x 4 mm protected
500 mAh cell was never a sourced part. No verified drop-in 500 mAh pack was found.
Keep the 500 mAh objective, but recommend the tray/depth changes below. No CAD,
PCB, firmware, generated BOM or purchased-part package was changed in this pass.

## Exact procurement candidates

| Role | Manufacturer / exact ordering identity | Selection and required change |
|---|---|---|
| Battery, 1 | LiPol Battery Co. Ltd **LP502540**, protected version, factory UL1571 AWG28 50 mm leads | 3.7 V, 500 mAh; product page says 40 x 25 x 5 mm, manufacturer's capacity list says 41 mm long. Use 41 mm only as a preliminary envelope, NOT a guaranteed maximum. Requires wider/longer tray and more rear clearance. Order only after supplier confirms protected finished-pack drawing, tolerances, swelling allowance and current limits. Bare leads; connector not included. |
| Speaker, 1 | Same Sky **CMS-16093-078L100** | Wired variant, 16 x 9 x 3 mm, 8 ohm, 0.7 W nominal / 1 W maximum. Replace circular ring with rectangular rim-supported seat, gasket and separated acoustic back volume. Its 18.36 mm diagonal does NOT fit the current 16.6 mm circular seat. Do not buy the spring-contact `078S` variant. |
| Record button, 1 | C&K / Littelfuse **PTS841GKSMTR LFS** | Side-actuated SMT, 3.6 x 3.5 mm outline, 1.25 mm height; distributor lists 250 gf and 0.20 mm travel. Replace top-actuated PTS645 on PCB and design a captured side plunger with a hard stop. Current side opening Z/XY is not matched to this switch. Exact footprint/drawing still needs onboarding. |
| Standby switch, 1 | C&K **JS202011AQN** | Retain existing exact part for low-current EN/AMP_SD standby only. NOT a whole-device battery disconnect: 0.3 A rating does not cover the unresolved total load. Existing library's recorder-current assumption is not accepted as a system current budget. Verify actuator reach and underside tails. |
| Speaker PCB connector, 1 | JST **BM02B-SRSS-TB(LF)(SN)** | Proposed 1 mm SH, top-entry SMT replacement for J2 PH through-hole header. Avoids solder tails beneath J2 and prevents ordinary mating with the PH battery plug. Full connector/mated-wire envelope still needs drawing verification and PCB change. |
| Speaker cable mating set, 1 | JST **SHR-02V-S-B**, two **SSH-003T-P0.2-H** contacts | Assemble an AWG28 harness with qualified crimps; verify speaker lead gauge before crimping directly, otherwise use insulated splices and strain relief. SH series rating is 1 A with AWG28. Pin 1 speaker +, pin 2 speaker −; neither amplifier output is ground. |
| Battery mating housing, 1 | JST **PHR-2**, two **SPH-002T-P0.5S** contacts | Proposed termination of factory cell leads to existing J1 **B2B-PH-K-S**. Confirm contact wire/insulation range and tooling against PH drawing before assembly. Verify actual polarity with a meter before connection: board pin 1 BAT+, pin 2 BAT−. Never infer polarity from housing or wire color alone. J1 tail clearance remains a blocker. |
| Clothing magnets, 8 | supermagnete **S-04-01-N** | Diameter 4 x 1 mm, N45, nickel plated; four opposed pairs. Nominally compatible with current 4.3 x 1.1/1.15 mm pockets, subject to adhesive and encapsulation allowance. Published ~250 g direct-contact attraction is NOT holding force through shell walls and fabric. Prototype retention before accepting. |

Retain existing Seeed **113991115** XIAO ESP32S3 Sense and
**MAX98357AETE+T** amplifier; no new module selection or stack-fit approval is
implied. Preserve camera-free use. Microphone inlet, Sense stack and antenna/coax
still need exact revision metrology. Do not substitute generic headers for them.

## Fit and electrical gates

1. Request LP502540 finished protected-pack drawing: 40/41 mm length conflict,
   maximum thickness, lead exit, protection-board position and expansion allowance.
   Preliminary tray cavity 26 x 42 mm gives only 0.5 mm nominal clearance per side;
   revise from supplier tolerances, not this allocation alone. Existing tray locator
   lugs at X +/-12.2 conflict with a wider tray and must move. Nominal shell internal
   width is 29 mm before local features; verify all surrounding geometry.
2. Existing rear floor is Z=-5 mm; tray floor top is -4.25 mm. A 5 mm cell would
   extend to +0.75 mm, intersecting the PCB at Z=0. Rear depth must increase or the
   architecture change. A preliminary rear_z=8.5 mm gives cell top -1.25 mm, but
   this is NOT approved swelling, insulation or solder-tail clearance.
3. LP502540 supplier lists charge 0.2–0.5 C (100–250 mA), discharge 0.5–1 C
   (250–500 mA). Confirm maximum continuous/pulse limits and PCM trip behavior.
   Measure recording/Wi-Fi/playback peaks before accepting the pack. Limit playback
   and concurrency if needed; 500 mAh capacity does not establish adequate current.
   Verify XIAO charging current, termination under load and temperature behavior.
   The listed pack has no NTC. Hard battery isolation remains a separate design task.
4. Speaker continuous power must remain within 0.7 W. Equivalent sine voltage is
   sqrt(0.7*8)=2.37 Vrms across the speaker, not to ground. Set amplifier gain and
   a measured firmware output ceiling; do not assume MAX98357 full scale is safe.
   Required acoustic volume and gasket compression are not established.
5. Replace J2 footprint and SW1 package only after exact drawing/pin/land-pattern
   validation. Preserve the current physical board before any source synchronization.
   Battery/SH connector cross-mating prevention does not replace polarity checks.
6. Fasteners are intentionally NOT ordered yet. Current lid screw channels run from
   near PCB height to the front face, so an arbitrary M2x6 screw will not secure
   them. Select exact screw length/thread/head after revised Z stack and boss design;
   qualify PA12 pilot hole, torque and cell separation. Mic gasket, grille mesh,
   adhesive and breakaway tether also remain specification/test-dependent.

## Rejected alternatives

- Adafruit **1578**, protected 500 mAh: approximately 29 x 36 x 4.75 mm.
  Its width consumes the nominal entire 29 mm shell cavity before tray and clearance;
  rejected for the unchanged 32 mm exterior.
- Adafruit **3898**, protected 400 mAh: approximately 36 x 17 x 7.8 mm.
  Narrow, but thicker and below capacity target; not a drop-in fallback.
- LP502030, 250 mAh: lower capacity and listed discharge up to 250 mA; not accepted
  merely because its width is near the placeholder.

## Sources and evidence

Manufacturer/distributor pages read during selection:

- Battery: https://www.lipolbattery.com/Lithium-Ion-Polymer-Battery-LP502540.html
- Conflicting length: https://www.lipolbattery.com/LiPo-Battery-500mAh+.html
- Speaker: https://www.sameskydevices.com/product/audio/speakers/miniature-(10-mm~40-mm)/cms-16093-078l100
- Speaker drawing to validate before CAD: https://www.sameskydevices.com/product/resource/cms-16093-078x.pdf
- Record switch series: https://www.littelfuse.com/products/switches/tactile-switches/pts841
- Exact switch variant: https://www.digikey.com/en/products/detail/c-k/PTS841GKSMTR-LFS/10445315
- SH series: https://www.jst-mfg.com/product/detail_e.php?series=231
- Exact SH header: https://www.jst-mfg.com/product/search_nomen_e.php?nomen=BM02B-SRSS-TB&search=Search
- Magnets: https://www.supermagnete.de/eng/disc-magnets-neodymium/disc-magnet-4mm-1mm_S-04-01-N
- Rejected battery sources: https://www.adafruit.com/product/1578 and https://www.adafruit.com/product/3898

Library searches returned no suitable battery/speaker records (unrelated regulator,
amplifier and MCU results were rejected), nor exact new switch/SH header packages.
JS202011AQN record was inspected; its existing package is reported validated with
pcb 0.3.71-rishabh.2, not freshly validated here. New parts have not been installed
or represented with fabricated placeholder footprints.

Validation here: source/document inspection, manufacturer-page comparison and
nominal envelope arithmetic only. No CAD rebuild, interference analysis, electrical
checks, acoustic/RF/thermal tests, live stock confirmation or hardware fit tests.
This is an actionable exact-part shortlist with explicit acceptance gates, not an
approved complete purchasing BOM or a claim that the existing enclosure fits.

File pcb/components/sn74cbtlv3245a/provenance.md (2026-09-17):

# SN74CBTLV3245APWR
TI PW TSSOP-20; datasheet ds_237ea3883d65e493dc22, pin table section 3,
PW0020A land-pattern drawing. Symbol authored from that pin table.
Footprint reused from installed KiCad 10 Package_SO TSSOP-20_4.4x6.5mm_P0.65mm
(KiCad libraries CC-BY-SA-4.0 with library exception); 20 pins, 0.65 mm pitch.
Ultra Librarian exact-part CAD listing was found but requires an external downloader.
No custom STEP is created. Stock KiCad package model is a package representation,
not an enclosure-fit validation.
Ioff provides powered-off isolation; OE high disconnects all eight bidirectional channels.

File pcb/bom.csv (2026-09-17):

Quantity | References | Populate | Value | Package | Mount | Manufacturer | MPN | Supplier | Supplier Part Number | Alternatives | Description | Datasheet | Configuration | Zener Paths | Source URL | Currency | Unit Price | Extended Price | Stock | Availability | Sourcing Updated
6 | C1 C3 C4 C5 C9 C10 | Yes | 100nF 50V X7R | 0603 |  | Murata | GCM188R71H104KA57J |  |  |  | 100nF 50V X7R |  | Configured | ai_pendant_recorder.zen:<root>.C1.C | ai_pendant_recorder.zen:<root>.C3.C | ai_pendant_recorder.zen:<root>.C4.C | ai_pendant_recorder.zen:<root>.C5.C | ai_pendant_recorder.zen:<root>.C9.C | ai_pendant_recorder.zen:<root>.C10.C | https://www.digikey.in/en/products/detail/murata-electronics/GCM188R71H104KA57J/4380305
7 | C2 C7 C8 C11 C12 C43 C44 | Yes | 10uF 25V X5R | 0805 |  | YAGEO | CC0805KRX5R8BB106 |  |  |  | 10uF 25V X5R |  | Configured | ai_pendant_recorder.zen:<root>.C2.C | ai_pendant_recorder.zen:<root>.C7.C | ai_pendant_recorder.zen:<root>.C8.C | ai_pendant_recorder.zen:<root>.C11.C | ai_pendant_recorder.zen:<root>.C12.C | ai_pendant_recorder.zen:<root>.C43.C | ai_pendant_recorder.zen:<root>.C44.C | https://www.mouser.in/en/ProductDetail/YAGEO/CC0805KRX5R8BB106?qs=CNuWj9FTWYDQ%252BJODP2bXGA%3D%3D
2 | C13 C14 | Yes | 22uF 10V X5R | 0805 |  | Murata | GRM21BR61A226ME44L |  |  |  | 22uF 10V X5R |  | Configured | ai_pendant_recorder.zen:<root>.C13.C | ai_pendant_recorder.zen:<root>.C14.C | https://www.mouser.in/en/ProductDetail/Murata-Electronics/GRM21BR61A226ME44L?qs=eeBpzGFlv%2B8tSfxib2AMhw%3D%3D
27 | C15 C16 C17 C18 C19 C20 C21 C22 C23 C24 C25 C26 C27 C28 C29 C30 C31 C32 C33 C34 C35 C36 C37 C38 C39 C45 C46 | Yes | 100nF 16V X7R | 0402 |  | Murata | GRM155R71C104KA88D | element14 | 4326785 |  | 100nF 16V X7R |  | Configured | ai_pendant_recorder.zen:<root>.C15.C | ai_pendant_recorder.zen:<root>.C16.C | ai_pendant_recorder.zen:<root>.C17.C | ai_pendant_recorder.zen:<root>.C18.C | ai_pendant_recorder.zen:<root>.C19.C | ai_pendant_recorder.zen:<root>.C20.C | ai_pendant_recorder.zen:<root>.C21.C | ai_pendant_recorder.zen:<root>.C22.C | ai_pendant_recorder.zen:<root>.C23.C | ai_pendant_recorder.zen:<root>.C24.C | ai_pendant_recorder.zen:<root>.C25.C | ai_pendant_recorder.zen:<root>.C26.C | ai_pendant_recorder.zen:<root>.C27.C | ai_pendant_recorder.zen:<root>.C28.C | ai_pendant_recorder.zen:<root>.C29.C | ai_pendant_recorder.zen:<root>.C30.C | ai_pendant_recorder.zen:<root>.C31.C | ai_pendant_recorder.zen:<root>.C32.C | ai_pendant_recorder.zen:<root>.C33.C | ai_pendant_recorder.zen:<root>.C34.C | ai_pendant_recorder.zen:<root>.C35.C | ai_pendant_recorder.zen:<root>.C36.C | ai_pendant_recorder.zen:<root>.C37.C | ai_pendant_recorder.zen:<root>.C38.C | ai_pendant_recorder.zen:<root>.C39.C | ai_pendant_recorder.zen:<root>.C45.C | ai_pendant_recorder.zen:<root>.C46.C | https://in.element14.com/murata/grm155r71c104ka88d/cap-mlcc-0-1uf-x7r-16v-0402/dp/4326785
3 | C40 C41 C42 | Yes | 1nF 25V C0G | 0402 |  | Murata | GRM1555C1E102JA01D |  |  |  | 1nF 25V C0G |  | Configured | ai_pendant_recorder.zen:<root>.C40.C | ai_pendant_recorder.zen:<root>.C41.C | ai_pendant_recorder.zen:<root>.C42.C | https://www.mouser.in/en/ProductDetail/Murata-Electronics/GRM1555C1E102JA01D?qs=y02iAgv9n62vwTD5aUQSxQ%3D%3D
1 | D1 | Yes |  | NSVR0320 |  | onsemi | NSVR0320MW2T1G |  |  |  |  |  | Configured | ai_pendant_recorder.zen:<root>.D1.D | https://in.element14.com/on-semiconductor/nsvr0320mw2t1g/schottky-diode-20v-sod-323/dp/2533249
2 | J1 J3 | Yes |  | JST_PH_B2B-PH-K_1x02_P2.00mm_Vertical |  | J.S.T. Mfg. Co., Ltd. | B2B-PH-K-S | DigiKey | 455-1704-ND |  | JST PH series 2-position top-entry shrouded through-hole header, 2.00 mm pitch. |  | Configured | ai_pendant_recorder.zen:<root>.J1.J_B2B_PH_K_S | ai_pendant_recorder.zen:<root>.J3.J_B2B_PH_K_S | https://www.digikey.in/en/products/detail/jst-sales-america-inc/B2B-PH-K-S/926611
1 | J4 | Yes |  | Molex_104031-0811 |  | Molex | 104031-0811 |  |  |  | Active 1.42 mm push-pull microSD socket; front entry; normally-open card detect | https://www.molex.com/content/dam/molex/molex-dot-com/products/automated/en-us/salesdrawingpdf/104/104031/1040310811_sd.pdf | Configured | ai_pendant_recorder.zen:<root>.J4.SD | https://www.mouser.in/en/ProductDetail/Molex/104031-0811?qs=udsGRKD4nA3Tvy7wqky%252BuA%3D%3D
1 | L1 | Yes |  | XEL4030_102MEC |  | Coilcraft | XEL4030-102MEC |  |  |  | 1 uH +/-20%, 9 A Isat, 9.78 mOhm max DCR shielded inductor | https://www.coilcraft.com/getmedia/8245f050-f190-4295-8c41-7c03d662ee3d/xel4030.pdf | Configured | ai_pendant_recorder.zen:<root>.L1.L | https://www.mouser.in/en/ProductDetail/Coilcraft/XEL4030-102MEC?qs=chTDxNqvsynxP6L4IWrGOQ%3D%3D
25 | LED1 LED2 LED3 LED4 LED5 LED6 LED7 LED8 LED9 LED10 LED11 LED12 LED13 LED14 LED15 LED16 LED17 LED18 LED19 LED20 LED21 LED22 LED23 LED24 LED25 | Yes |  | WS2812C_2020_V1 |  | Worldsemi | WS2812C-2020-V1 | LCSC | C2976072 |  | 2.0 mm addressable RGB LED, 5 mA/channel, 3.7-5.3 V, LCSC C2976072 | https://datasheet.lcsc.com/datasheet/pdf/09f4c697250f44092a00c11d7628f2c6.pdf?productCode=C2976072 | Configured | ai_pendant_recorder.zen:<root>.LED1.RGB | ai_pendant_recorder.zen:<root>.LED2.RGB | ai_pendant_recorder.zen:<root>.LED3.RGB | ai_pendant_recorder.zen:<root>.LED4.RGB | ai_pendant_recorder.zen:<root>.LED5.RGB | ai_pendant_recorder.zen:<root>.LED6.RGB | ai_pendant_recorder.zen:<root>.LED7.RGB | ai_pendant_recorder.zen:<root>.LED8.RGB | ai_pendant_recorder.zen:<root>.LED9.RGB | ai_pendant_recorder.zen:<root>.LED10.RGB | ai_pendant_recorder.zen:<root>.LED11.RGB | ai_pendant_recorder.zen:<root>.LED12.RGB | ai_pendant_recorder.zen:<root>.LED13.RGB | ai_pendant_recorder.zen:<root>.LED14.RGB | ai_pendant_recorder.zen:<root>.LED15.RGB | ai_pendant_recorder.zen:<root>.LED16.RGB | ai_pendant_recorder.zen:<root>.LED17.RGB | ai_pendant_recorder.zen:<root>.LED18.RGB | ai_pendant_recorder.zen:<root>.LED19.RGB | ai_pendant_recorder.zen:<root>.LED20.RGB | ai_pendant_recorder.zen:<root>.LED21.RGB | ai_pendant_recorder.zen:<root>.LED22.RGB | ai_pendant_recorder.zen:<root>.LED23.RGB | ai_pendant_recorder.zen:<root>.LED24.RGB | ai_pendant_recorder.zen:<root>.LED25.RGB | https://www.lcsc.com/product-detail/C2976072.html
1 | MK1 | Yes |  | IM69D130 |  | Infineon | IM69D130V01XTSA1 | element14 | 2986420 |  | Bottom-port PDM microphone; SELECT low; place 100nF at VDD and provide PCB acoustic opening | https://www.infineon.com/row/public/documents/24/49/infineon-im69d130-datasheet-en.pdf | Configured | ai_pendant_recorder.zen:<root>.MK1.MIC | https://in.element14.com/infineon/im69d130v01xtsa1/mems-microphone-3-6v-module/dp/2986420
2 | Q1 Q2 | Yes |  | SOT-23 |  | Alpha & Omega Semiconductor | AO3400A |  |  |  | Alpha & Omega Semiconductor AO3400A 30 V N-channel MOSFET in SOT-23 | https://www.aosmd.com/res/datasheets/AO3400A.pdf | Configured | ai_pendant_recorder.zen:<root>.Q1.Q_AO3400A | ai_pendant_recorder.zen:<root>.Q2.Q_AO3400A | https://www.digikey.in/en/products/detail/alpha-omega-semiconductor-inc/AO3400A/1855772
6 | R1 R8 R23 R26 R27 R29 | Yes | 100k 100mW | 0603 |  | YAGEO | RC0603FR-07100KL | DigiKey | 311-100KHRCT-ND |  | 100k 100mW |  | Configured | ai_pendant_recorder.zen:<root>.R1.R | ai_pendant_recorder.zen:<root>.R8.R | ai_pendant_recorder.zen:<root>.R23.R | ai_pendant_recorder.zen:<root>.R26.R | ai_pendant_recorder.zen:<root>.R27.R | ai_pendant_recorder.zen:<root>.R29.R | https://www.digikey.in/en/products/detail/yageo/RC0603FR-07100KL/726889
3 | R4 R5 R30 | Yes | 4.7k 100mW | 0603 |  | YAGEO | RC0603FR-074K7L |  |  |  | 4.7k 100mW |  | Configured | ai_pendant_recorder.zen:<root>.R4.R | ai_pendant_recorder.zen:<root>.R5.R | ai_pendant_recorder.zen:<root>.R30.R | https://www.digikey.in/en/products/detail/yageo/RC0603FR-074K7L/727212
1 | R7 | Yes | 100 100mW | 0603 |  | YAGEO | RC0603FR-07100RL |  |  |  | 100 100mW |  | Configured | ai_pendant_recorder.zen:<root>.R7.R | https://www.digikey.in/en/products/detail/yageo/RC0603FR-07100RL/726888
2 | R16 R17 | Yes | 33 100mW | 0603 |  | YAGEO | RC0603FR-0733RL | element14 | 9238301 |  | 33 100mW |  | Configured | ai_pendant_recorder.zen:<root>.R16.R | ai_pendant_recorder.zen:<root>.R17.R | https://in.element14.com/yageo/rc0603fr-0733rl/res-33r-1-0-1w-0603-thick-film/dp/9238301
5 | R18 R19 R20 R21 R22 | Yes | 47k 100mW | 0603 |  | YAGEO | RC0603FR-0747KL | element14 | 9238689 |  | 47k 100mW |  | Configured | ai_pendant_recorder.zen:<root>.R18.R | ai_pendant_recorder.zen:<root>.R19.R | ai_pendant_recorder.zen:<root>.R20.R | ai_pendant_recorder.zen:<root>.R21.R | ai_pendant_recorder.zen:<root>.R22.R | https://in.element14.com/yageo/rc0603fr-0747kl/res-47k-1-0-1w-0603-thick-film/dp/9238689
1 | R25 | Yes | 732k 100mW | 0603 |  | YAGEO | RC0603FR-07732KL |  |  |  | 732k 100mW |  | Configured | ai_pendant_recorder.zen:<root>.R25.R | https://www.digikey.com/en/products/detail/yageo/RC0603FR-07732KL/727376
1 | R28 | Yes | 470 100mW | 0603 |  | YAGEO | RC0603FR-07470RL | DigiKey | 311-470HRCT-ND |  | 470 100mW |  | Configured | ai_pendant_recorder.zen:<root>.R28.R | https://www.digikey.com/en/products/detail/yageo/RC0603FR-07470RL/727256
1 | SW1 | Yes |  | PTS841GK |  | C&K | PTS841GKSMTR LFS | DigiKey | 108-PTS841GKSMTRLFSCT-ND |  |  |  | Configured | ai_pendant_recorder.zen:<root>.SW1.SW_PTS841 | https://www.digikey.com/en/products/detail/c-k/PTS841GKSMTR-LFS/10445315
1 | SW2 | Yes |  | SW_CK_JS202011AQN_DPDT_Angled |  | C&K | JS202011AQN | DigiKey | 401-2000-ND |  | C&K JS202011AQN DPDT ON-ON slide switch, right-angle THT, 0.3 A at 6 VDC | https://www.ckswitches.com/media/1422/js.pdf | Configured | ai_pendant_recorder.zen:<root>.SW2.SW_JS202011AQN | https://www.digikey.in/en/products/detail/c-k/JS202011AQN/1640096
1 | U1 | Yes |  | XIAO |  | Seeed Studio | 113991114 |  |  |  | Base XIAO ESP32S3, no Sense expansion, direct-solder SMD | https://wiki.seeedstudio.com/xiao_esp32s3_getting_started/ | Configured | ai_pendant_recorder.zen:<root>.U1.XIAO | https://www.seeedstudio.com/XIAO-ESP32S3-p-5627.html
1 | U3 | Yes |  | kicad_footprint |  | Analog Devices | MAX17048G+T10 |  |  |  | Analog Devices/Maxim MAX17048G+T10 1-cell Li+ ModelGauge fuel gauge, 8-TDFN-EP | https://www.analog.com/media/en/technical-documentation/data-sheets/max17048-max17049.pdf | Configured | ai_pendant_recorder.zen:<root>.U3.FG | https://www.digikey.in/en/products/detail/analog-devices-inc-maxim-integrated/MAX17048G-T10/3758921
1 | U4 | Yes |  | BMI270 |  | Bosch Sensortec | BMI270 |  |  |  |  | https://www.bosch-sensortec.com/media/boschsensortec/downloads/datasheets/bst-bmi270-ds000.pdf | Configured | ai_pendant_recorder.zen:<root>.U4.IMU | https://www.digikey.in/en/products/detail/bosch-sensortec/BMI270/9974486
1 | U5 | Yes |  | DRL0006A SOT-563 |  | Texas Instruments | TPS61023DRLR |  |  |  | TI TPS61023DRLR 0.5 V to 5.5 V, 3.7 A synchronous boost converter | https://www.ti.com/lit/ds/symlink/tps61023.pdf | Configured | ai_pendant_recorder.zen:<root>.U5.U_TPS61023 | https://www.mouser.in/en/ProductDetail/Texas-Instruments/TPS61023DRLR?qs=BJlw7L4Cy7%2FfEnwYuWeGOg%3D%3D
1 | U6 | Yes |  | AP2112K_3V3 |  | Diodes Incorporated | AP2112K-3.3TRG1 | element14 | 3257429 |  |  |  | Configured | ai_pendant_recorder.zen:<root>.U6.LDO | https://in.element14.com/diodes-inc/ap2112k-3-3trg1/ldo-fixed-3-3v-0-6a-sot-25-85deg/dp/3257429
3 | U7 U8 U9 | Yes |  | DBV SOT-23-6 |  | Texas Instruments | TPS22918DBVR |  |  |  | TI TPS22918DBVR 1 V to 5.5 V, 2 A, 52 mOhm load switch | https://www.ti.com/lit/gpn/TPS22918 | Configured | ai_pendant_recorder.zen:<root>.U7.U_TPS22918 | ai_pendant_recorder.zen:<root>.U8.U_TPS22918 | ai_pendant_recorder.zen:<root>.U9.U_TPS22918 | https://www.mouser.in/ProductDetail/Texas-Instruments/TPS22918DBVR?qs=f4l5qYp%2Fy%252B5F7w5ZAgmi7A%3D%3D
2 | U10 U11 | Yes |  | TSSOP-20 |  | Texas Instruments | SN74CBTLV3245APWR |  |  |  |  | https://www.ti.com/lit/ds/symlink/sn74cbtlv3245a.pdf | Configured | ai_pendant_recorder.zen:<root>.U10.BUS | ai_pendant_recorder.zen:<root>.U11.BUS

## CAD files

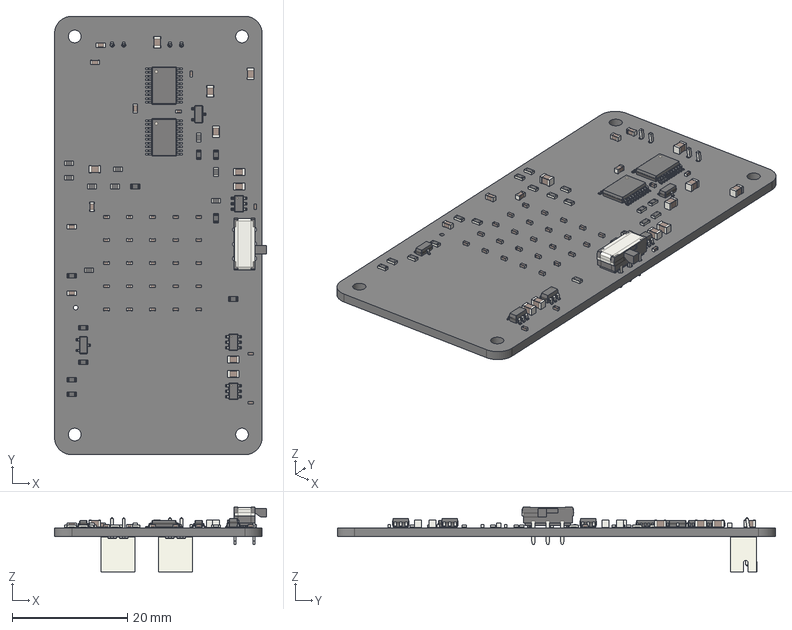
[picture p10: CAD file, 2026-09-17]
mechanical/imports/populated-pcb.step
36.8 x 76.0 x 11.2 mm
R_0603_1608Metric x 19
C_0402_1005Metric x 30
SOT-23-6 x 3
C_0805_2012Metric x 9
TSSOP-20_4.4x6.5mm_P0.65mm x 2
SOT-23 x 2
C_0603_1608Metric x 6
SW_CK_JS202011AQN_DPDT_Angled
JST_PH_B2B-PH-K_1x02_P2.00mm_Vertical x 2
layout_PCB

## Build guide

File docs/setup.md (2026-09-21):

# Firmware setup

Entry point: `src/main.cpp`; framework: Arduino/PlatformIO.
Environment `esp32-s3` selects the Seeed XIAO ESP32S3 board definition with
`esp-builtin`. A successful build is still required before flashing.

Use a qualified FAT32 microSD card; microphone is the external carrier PDM
IM69D130, not a Sense expansion microphone. See [pin map](current-design.md).
Network configuration is presently unused. Never commit real credentials.
Bench-test rail droop, charge behavior, SD writes, audio and LED sequencing.

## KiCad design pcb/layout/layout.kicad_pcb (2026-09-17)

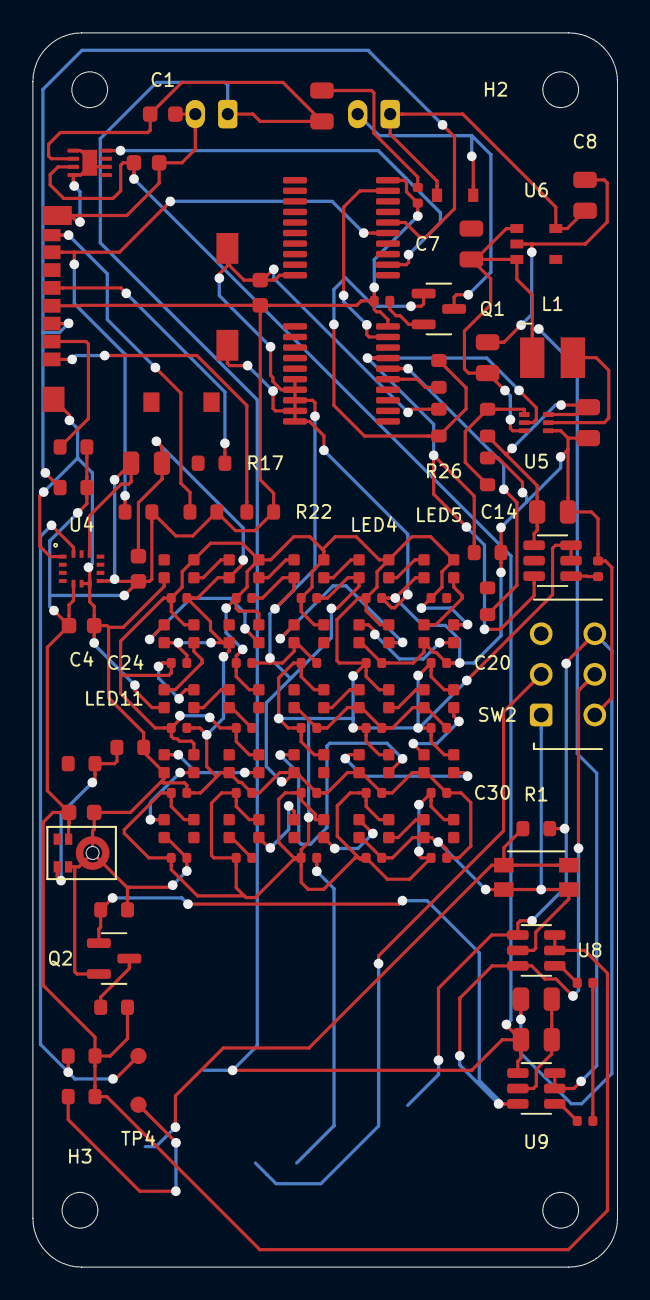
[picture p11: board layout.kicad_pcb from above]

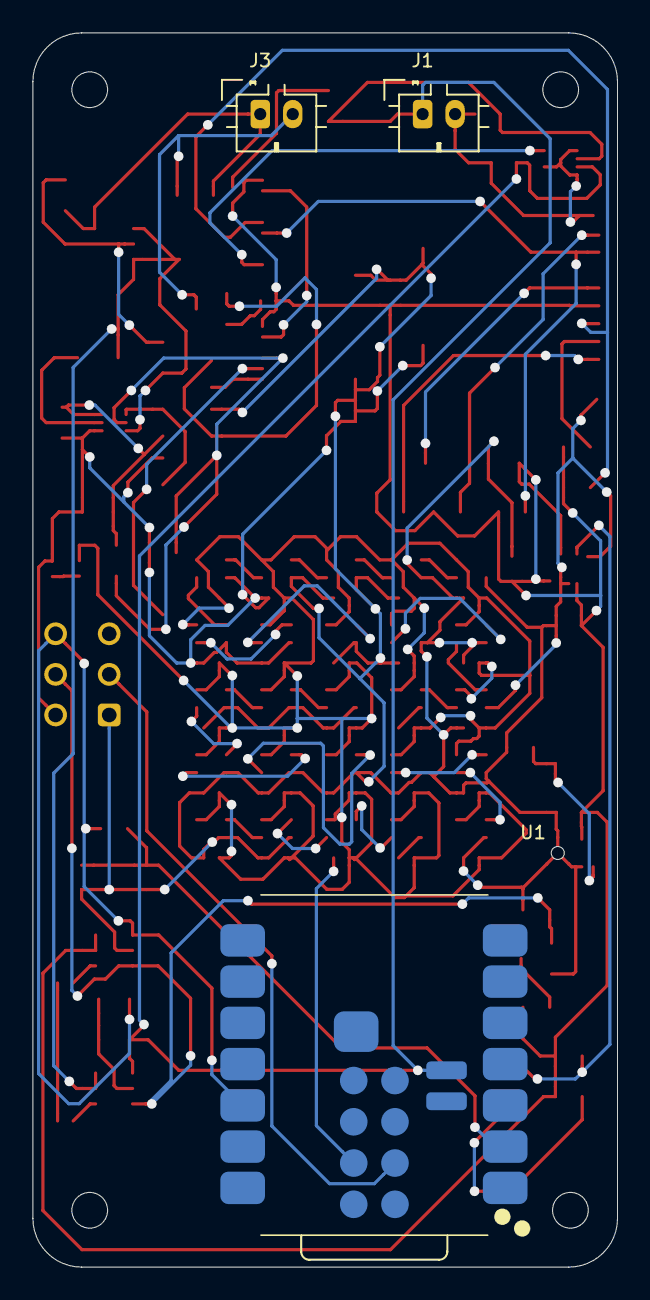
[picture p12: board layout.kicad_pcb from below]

Board: 2 copper layers, 36.0 x 76.0 mm, 115 parts (3 on the bottom side), 72 nets.

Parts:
C1, C3, C4, C5, C9, C10: GCM188R71H104KA57J; C_0603_1608Metric
C2, C7, C8, C11, C12, C43, C44: CC0805KRX5R8BB106; C_0805_2012Metric
C13, C14: GRM21BR61A226ME44L; C_0805_2012Metric
C15, C16, C17, C18, C19, C20, C21, C22, C23, C24, C25, C26, C27, C28, C29, C30, C31, C32, C33, C34, C35, C36, C37, C38, C39, C45, C46: GRM155R71C104KA88D; C_0402_1005Metric
C40, C41, C42: GRM1555C1E102JA01D; C_0402_1005Metric
D1: NSVR0320MW2T1G; NSVR0320
H1, H2, H3, H4: M2 DIN965 Mechanical; MountingHole_2.2mm_M2_DIN965
J1, J3: B2B-PH-K-S; JST_PH_B2B-PH-K_1x02_P2.00mm_Vertical
J4: 104031-0811; Molex_104031-0811
L1: XEL4030-102MEC; XEL4030_102MEC
LED1, LED2, LED3, LED4, LED5, LED6, LED7, LED8, LED9, LED10, LED11, LED12, LED13, LED14, LED15, LED16, LED17, LED18, LED19, LED20, LED21, LED22, LED23, LED24, LED25: WS2812C-2020-V1; WS2812C_2020_V1
MK1: IM69D130V01XTSA1; IM69D130
Q1, Q2: AO3400A; SOT-23
R1, R8, R23, R26, R27, R29: RC0603FR-07100KL; R_0603_1608Metric
R4, R5, R30: RC0603FR-074K7L; R_0603_1608Metric
R7: RC0603FR-07100RL; R_0603_1608Metric
R16, R17: RC0603FR-0733RL; R_0603_1608Metric
R18, R19, R20, R21, R22: RC0603FR-0747KL; R_0603_1608Metric
R25: RC0603FR-07732KL; R_0603_1608Metric
R28: RC0603FR-07470RL; R_0603_1608Metric
SW1: PTS841GKSMTR LFS; PTS841GK
SW2: JS202011AQN; SW_CK_JS202011AQN_DPDT_Angled
TP3, TP4: ?; TestPoint_Pad_D1.0mm
U1: 113991114; XIAO
U3: MAX17048G+T10; kicad_footprint
U4: BMI270
U5: TPS61023DRLR; Texas_R-PDSO-N6_DRL-6
U6: AP2112K-3.3TRG1; AP2112K_3V3
U7, U8, U9: TPS22918DBVR; SOT-23-6
U10, U11: SN74CBTLV3245APWR; TSSOP-20

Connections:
BAT_RISE: C42.1, U9.4
BOOST_5V: C13.1, C14.1, R25.1, U5.6, U7.1
FG_SCL: R5.1, TP4.1, U3.7, U4.13, U10.11
FG_SDA: R4.1, TP3.1, U3.8, U4.14, U10.12
GND: C1.2, C2.2, C3.2, C4.2, C5.2, C7.2, C8.2, C9.2, C10.2, C11.2, C12.2, C13.2, C14.2, C15.2, C16.2, C17.2, C18.2, C19.2, C20.2, C21.2, C22.2, C23.2, C24.2, C25.2, C26.2, C27.2, C28.2, C29.2, C30.2, C31.2, C32.2, C33.2, C34.2, C35.2, C36.2, C37.2, C38.2, C39.2, C40.2, C41.2, C42.2, C43.2, C44.2, C45.2, C46.2, J1.2, J4.6, J4.11, LED1.2, LED2.2, LED3.2, LED4.2, LED5.2, LED6.2, LED7.2, LED8.2, LED9.2, LED10.2, LED11.2, LED12.2, LED13.2, LED14.2, LED15.2, LED16.2, LED17.2, LED18.2, LED19.2, LED20.2, LED21.2, LED22.2, LED23.2, LED24.2, LED25.2, MK1.4, MK1.5, Q1.2, Q2.2, R8.2, R23.2, R26.2, R27.2, R29.2, SW1.3, SW1.4, SW2.1, SW2.4, U1.13, U1.18, U1.24, U3.1, U3.4, U3.6, U3.9, U4.1, U4.6, U4.7, U5.4, U6.2, U7.2, U8.2, U9.2, U10.10, U11.6, U11.7, U11.8, U11.9, U11.10
HAPTIC_DRIVE: R7.1, U11.15
HOST_HAPTIC: U1.1, U11.5
HOST_IMU_INT: U1.16, U11.2
HOST_LED_DATA: U1.4, U11.4
HOST_LED_ENABLE: U1.3, U11.3
HOST_PDM_CLK: U1.19, U10.6
HOST_PDM_DATA: U1.15, U10.7
HOST_SCL: U1.6, U10.9
HOST_SDA: U1.5, U10.8
HOST_SD_CLK: U1.9, U10.2
HOST_SD_CS: U1.20, U10.3
HOST_SD_MISO: U1.10, U10.5
HOST_SD_MOSI: U1.11, U10.4
IMU_INT: U4.4, U11.18
ISOLATE_N: Q2.3, R30.1, U10.19, U11.19
LED_5V: C15.1, C16.1, C17.1, C18.1, C19.1, C20.1, C21.1, C22.1, C23.1, C24.1, C25.1, C26.1, C27.1, C28.1, C29.1, C30.1, C31.1, C32.1, C33.1, C34.1, C35.1, C36.1, C37.1, C38.1, C39.1, LED1.4, LED2.4, LED3.4, LED4.4, LED5.4, LED6.4, LED7.4, LED8.4, LED9.4, LED10.4, LED11.4, LED12.4, LED13.4, LED14.4, LED15.4, LED16.4, LED17.4, LED18.4, LED19.4, LED20.4, LED21.4, LED22.4, LED23.4, LED24.4, LED25.4, U7.5, U7.6
LED_CHAIN_1: LED1.1, LED2.3
LED_CHAIN_2: LED2.1, LED3.3
LED_CHAIN_3: LED3.1, LED4.3
LED_CHAIN_4: LED4.1, LED5.3
LED_CHAIN_5: LED5.1, LED6.3
LED_CHAIN_6: LED6.1, LED7.3
LED_CHAIN_7: LED7.1, LED8.3
LED_CHAIN_8: LED8.1, LED9.3
LED_CHAIN_9: LED9.1, LED10.3
LED_CHAIN_10: LED10.1, LED11.3
LED_CHAIN_11: LED11.1, LED12.3
LED_CHAIN_12: LED12.1, LED13.3
LED_CHAIN_13: LED13.1, LED14.3
LED_CHAIN_14: LED14.1, LED15.3
LED_CHAIN_15: LED15.1, LED16.3
LED_CHAIN_16: LED16.1, LED17.3
LED_CHAIN_17: LED17.1, LED18.3
LED_CHAIN_18: LED18.1, LED19.3
LED_CHAIN_19: LED19.1, LED20.3
LED_CHAIN_20: LED20.1, LED21.3
LED_CHAIN_21: LED21.1, LED22.3
LED_CHAIN_22: LED22.1, LED23.3
LED_CHAIN_23: LED23.1, LED24.3
LED_CHAIN_24: LED24.1, LED25.3
LED_DATA: LED1.3, R28.2
LED_DATA_MCU: R28.1, U11.16
LED_ENABLE: R27.1, U5.2, U7.3, U11.17
LED_FB: R25.2, R26.1, U5.1
LED_RISE: C40.1, U7.4
LED_SW: L1.2, U5.5
MCU_EN: SW2.2, U1.17
MOTOR_3V3: C8.1, D1.1, J3.1, U6.5
MOTOR_GATE: Q1.1, R7.2, R8.1
MOTOR_N: D1.2, J3.2, Q1.3
PDM_CLK: MK1.3, R16.2, R23.1
PDM_CLK_MCU: R16.1, U10.14
PDM_DATA: MK1.1, U10.13
PERIPH_RISE: C41.1, U8.4
RECORD_BUTTON: R1.1, SW1.1, SW1.2, U1.2
RUN_ENABLE: Q2.1, R29.1, SW2.5, U8.3, U9.3
SD_CLK: J4.5, R17.2
SD_CLK_MCU: R17.1, U10.18
SD_CS: J4.2, R18.1, U10.17
SD_DAT1: J4.8, R21.1
SD_DAT2: J4.1, R22.1
SD_MISO: J4.7, R20.1, U10.15
SD_MOSI: J4.3, R19.1, U10.16
V3V3: C4.1, C5.1, C9.1, C10.1, C11.1, C45.1, C46.1, J4.4, MK1.2, R4.2, R5.2, R18.2, R19.2, R20.2, R21.2, R22.2, R30.2, U4.5, U4.8, U4.12, U8.5, U8.6, U10.20, U11.20
V3V3_AON: C43.1, R1.2, SW2.6, U1.12, U8.1
VBAT: C1.1, C2.1, C3.1, C44.1, J1.1, U1.23, U3.2, U3.3, U9.1
VBAT_PERIPH: C7.1, C12.1, L1.1, U5.3, U6.1, U6.3, U9.5, U9.6

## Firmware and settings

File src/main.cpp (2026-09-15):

#include <Arduino.h>
#include <SD.h>
#include <SPI.h>
#include <Preferences.h>
#include <Adafruit_NeoPixel.h>
#include "driver/i2s.h"
#include "audio_format.h"

namespace {
// Base XIAO ESP32S3 carrier contract; keep synchronized with pcb/ai_pendant_recorder.zen.
constexpr int recordButton=2, micClock=42, micData=41;
constexpr int ledEnable=3, ledData=4;
constexpr int hapticDrive=1;
constexpr int sdCS=39, sdSCK=7, sdMISO=8, sdMOSI=9;
constexpr uint16_t pixelCount=25;
// 25 low-current pixels can theoretically draw 375 mA. Keep animation output
// far below that until whole-system current and thermal limits are bench-tested.
constexpr uint8_t pixelBrightnessCap=24;
Adafruit_NeoPixel pixels(pixelCount,ledData,NEO_GRB+NEO_KHZ800);
struct Block { uint16_t size; uint8_t data[1024]; };
QueueHandle_t blocks;
EventGroupHandle_t events;
constexpr EventBits_t RUN=1, FAULT=2, ACTIVE=4;
// Reserved integration requests: producers set/clear requests; only animator
// owns the LED rail/data after setup. Future motor code must await LED_OFF.
constexpr EventBits_t LED_INHIBIT=8, LED_OFF=16, HEAVY_LOAD=32;
Preferences prefs;
File chunk;
String tempPath;
uint32_t dataBytes=0;

bool writeHeader(File& f, uint32_t bytes) {
  uint8_t h[44]; audio::wavHeader(h,bytes);
  return f.seek(0) && f.write(h,sizeof(h))==sizeof(h);
}

bool finishChunk() {
  if (!chunk) return true;
  bool ok=writeHeader(chunk,dataBytes);
  chunk.flush(); chunk.close();
  if (!ok) return false;
  String finalPath=tempPath.substring(0,tempPath.length()-5)+".wav";
  if (SD.exists(finalPath) || !SD.rename(tempPath,finalPath)) return false;
  Serial.printf("recording:finalized:%s:%lu\n",finalPath.c_str(),(unsigned long)dataBytes);
  return true;
}

bool openChunk() {
  if (SD.totalBytes() <= SD.usedBytes()+audio::chunkBytes+1024*1024) return false;
  // Reserve identity durably before creating the file. Never append after reboot.
  uint32_t id=prefs.getUInt("sequence",0);
  do {
    if (id==UINT32_MAX) return false;
    ++id;
    char name[40]; snprintf(name,sizeof(name),"/audio/%010lu.part",(unsigned long)id);
    tempPath=name;
  } while (SD.exists(tempPath) || SD.exists(tempPath.substring(0,tempPath.length()-5)+".wav"));
  if (prefs.putUInt("sequence",id)!=sizeof(id)) return false;
  chunk=SD.open(tempPath,FILE_WRITE);
  dataBytes=0;
  if (!chunk) return false;
  if (!writeHeader(chunk,0)) { chunk.close(); return false; }
  return true;
}

bool recover() {
  File dir=SD.open("/audio");
  if (!dir || !dir.isDirectory()) return false;
  // Recovery runs before recording tasks; rename only after the iterator closes.
  for (;;) {
    String candidate;
    File f=dir.openNextFile();
    while (f) {
      String n=f.name();
      if (!f.isDirectory() && n.endsWith(".part")) {
        candidate=n.startsWith("/") ? n : String("/audio/")+n;
        f.close(); break;
      }
      f.close(); f=dir.openNextFile();
    }
    dir.close();
    if (!candidate.length()) return true;
    File partial=SD.open(candidate,"r+");
    if (!partial || partial.size()<44) {
      if (partial) partial.close();
      // Keep damaged bytes for service; do not delete unsynced data.
      if (!SD.rename(candidate,candidate+".bad")) return false;
    } else {
      uint32_t bytes=(partial.size()-44)&~1U;
      bool ok=writeHeader(partial,bytes);
      partial.flush(); partial.close();
      String finalPath=candidate.substring(0,candidate.length()-5)+".wav";
      if (!ok || SD.exists(finalPath) || !SD.rename(candidate,finalPath)) return false;
      Serial.printf("recording:recovered:%s\n",finalPath.c_str());
    }
    dir=SD.open("/audio");
    if (!dir) return false;
  }
}

bool initMic() {
  i2s_config_t c={};
  c.mode=(i2s_mode_t)(I2S_MODE_MASTER|I2S_MODE_RX|I2S_MODE_PDM);
  c.sample_rate=audio::sampleRate; c.bits_per_sample=I2S_BITS_PER_SAMPLE_16BIT;
  c.channel_format=I2S_CHANNEL_FMT_ONLY_LEFT;
  c.communication_format=I2S_COMM_FORMAT_STAND_I2S;
  c.intr_alloc_flags=ESP_INTR_FLAG_LEVEL1; c.dma_buf_count=16; c.dma_buf_len=256;
  i2s_pin_config_t p={};
  p.mck_io_num=I2S_PIN_NO_CHANGE; p.bck_io_num=I2S_PIN_NO_CHANGE;
  p.ws_io_num=micClock; p.data_out_num=I2S_PIN_NO_CHANGE; p.data_in_num=micData;
  if (i2s_driver_install(I2S_NUM_0,&c,0,nullptr)!=ESP_OK) return false;
  if (i2s_set_pin(I2S_NUM_0,&p)==ESP_OK) return true;
  i2s_driver_uninstall(I2S_NUM_0); return false;
}

void acquire(void*) {
  Block b;
  for (;;) {
    // Keep draining DMA while idle, avoiding stale audio at start.
    size_t count=0;
    esp_err_t result=i2s_read(I2S_NUM_0,b.data,sizeof(b.data),&count,pdMS_TO_TICKS(100));
    if (result!=ESP_OK) { xEventGroupSetBits(events,FAULT); continue; }
    xEventGroupSetBits(events,ACTIVE);
    if (!(xEventGroupGetBits(events)&RUN)) { xEventGroupClearBits(events,ACTIVE); continue; }
    b.size=count & ~size_t(1);
    if (b.size && xQueueSend(blocks,&b,0)!=pdTRUE) xEventGroupSetBits(events,FAULT);
    xEventGroupClearBits(events,ACTIVE);
  }
}

void writer(void*) {
  Block b;
  bool lastRaw=false, pressed=false, recording=false, healthy=true;
  uint32_t changed=0;
  for (;;) {
    bool raw=digitalRead(recordButton)==LOW;
    if (raw!=lastRaw) { changed=millis(); lastRaw=raw; }
    if (raw!=pressed && millis()-changed>=35) {
      pressed=raw;
      if (pressed && healthy) {
        if (!recording && !chunk && uxQueueMessagesWaiting(blocks)==0 &&
            !(xEventGroupGetBits(events)&ACTIVE)) {
          if (openChunk()) { recording=true; xEventGroupSetBits(events,RUN); }
          else { healthy=false; Serial.println("recording:fault:open-or-full"); }
        } else if (recording) { recording=false; xEventGroupClearBits(events,RUN); }
      }
    }
    if (xEventGroupGetBits(events)&FAULT) {
      recording=false; healthy=false; xEventGroupClearBits(events,RUN);
    }
    if (xQueueReceive(blocks,&b,pdMS_TO_TICKS(5))==pdTRUE && healthy) {
      if (!chunk) healthy=openChunk();
      size_t offset=0;
      while (offset<b.size && healthy) {
        size_t n=min(size_t(b.size-offset),size_t(audio::chunkBytes-dataBytes));
        if (chunk.write(b.data+offset,n)!=n) { healthy=false; break; }
        dataBytes+=n; offset+=n;
        if (dataBytes==audio::chunkBytes) {
          healthy=finishChunk();
          if (healthy && (recording || offset<b.size)) healthy=openChunk();
        }
      }
    }
    if (!healthy) {
      recording=false; xEventGroupClearBits(events,RUN);
      if (chunk) { chunk.flush(); chunk.close(); } // preserve .part for recovery
      xQueueReset(blocks);
    } else if (!recording && !(xEventGroupGetBits(events)&ACTIVE) && uxQueueMessagesWaiting(blocks)==0) {
      healthy=finishChunk();
    }
    if (!healthy) { xEventGroupSetBits(events,FAULT); vTaskDelay(pdMS_TO_TICKS(100)); }
  }
}

uint16_t matrixIndex(uint8_t x,uint8_t y) {
  return uint16_t(y)*5U+((y&1U)?(4U-x):x);
}

void animator(void*) {
  uint8_t phase=0;
  bool powered=false;
  pixels.begin(); pixels.setBrightness(pixelBrightnessCap); pixels.clear();
  digitalWrite(ledData,LOW);
  xEventGroupSetBits(events,LED_OFF);
  for (;;) {
    EventBits_t state=xEventGroupGetBits(events);
    if (state&(FAULT|LED_INHIBIT)) {
      if (powered) {
        pixels.clear(); pixels.show();
        digitalWrite(ledData,LOW);
        vTaskDelay(pdMS_TO_TICKS(2)); // latch the black frame before rail removal
        digitalWrite(ledEnable,LOW); powered=false;
      }
      xEventGroupSetBits(events,LED_OFF);
      vTaskDelay(pdMS_TO_TICKS(20)); continue;
    }
    if (!powered) {
      xEventGroupClearBits(events,LED_OFF);
      digitalWrite(ledData,LOW);
      digitalWrite(ledEnable,HIGH);
      vTaskDelay(pdMS_TO_TICKS(10)); // provisional ramp margin; verify on scope
      pixels.clear(); pixels.show(); powered=true;
      vTaskDelay(pdMS_TO_TICKS(2));
      continue; // recheck inhibits before any lit frame
    }
    pixels.clear();
    if (state&RUN) {
      // Low-current red recording pulse: center plus four nearest neighbors.
      uint8_t level=uint8_t(10U+((phase<32?phase:63-phase)*2U));
      pixels.setPixelColor(matrixIndex(2,2),pixels.Color(level,0,0));
      pixels.setPixelColor(matrixIndex(2,1),pixels.Color(level/3,0,0));
      pixels.setPixelColor(matrixIndex(3,2),pixels.Color(level/3,0,0));
      pixels.setPixelColor(matrixIndex(2,3),pixels.Color(level/3,0,0));
      pixels.setPixelColor(matrixIndex(1,2),pixels.Color(level/3,0,0));
    } else {
      // Dim blue orbit around the perimeter; one lit pixel minimizes load.
      static const uint8_t orbit[16][2]={{0,0},{1,0},{2,0},{3,0},{4,0},{4,1},{4,2},{4,3},
        {4,4},{3,4},{2,4},{1,4},{0,4},{0,3},{0,2},{0,1}};
      const uint8_t* p=orbit[(phase/4U)%16U];
      pixels.setPixelColor(matrixIndex(p[0],p[1]),pixels.Color(0,6,28));
    }
    // Conservative recording/write-load reduction, without repeatedly changing
    // NeoPixel's lossy global brightness setting. Future upload uses HEAVY_LOAD.
    if (state&(RUN|HEAVY_LOAD)) {
      for (uint16_t i=0;i<pixelCount;++i) {
        uint32_t c=pixels.getPixelColor(i);
        pixels.setPixelColor(i,uint8_t(c>>16)/2,uint8_t(c>>8)/2,uint8_t(c)/2);
      }
    }
    pixels.show(); phase=(phase+1U)&63U;
    vTaskDelay(pdMS_TO_TICKS(40));
  }
}
}

void setup() {
  Serial.begin(115200);
  pinMode(recordButton,INPUT_PULLUP);
  pinMode(ledData,OUTPUT); digitalWrite(ledData,LOW);
  pinMode(ledEnable,OUTPUT); digitalWrite(ledEnable,LOW);
  pinMode(hapticDrive,OUTPUT); digitalWrite(hapticDrive,LOW);
  // No camera initialization, Wi-Fi connection, upload or automatic deletion.
  SPI.begin(sdSCK,sdMISO,sdMOSI,sdCS);
  if (!prefs.begin("recorder",false) || !SD.begin(sdCS,SPI,10000000) ||
      (!SD.exists("/audio") && !SD.mkdir("/audio")) || !recover()) {
    Serial.println("startup:fault:storage"); return;
  }
  blocks=xQueueCreate(32,sizeof(Block)); events=xEventGroupCreate();
  if (!blocks || !events || !initMic()) { Serial.println("startup:fault:audio-memory"); return; }
  TaskHandle_t acquisition=nullptr;
  if (xTaskCreatePinnedToCore(acquire,"capture",4096,nullptr,3,&acquisition,1)!=pdPASS) {
    Serial.println("startup:fault:capture-task"); return;
  }
  if (xTaskCreatePinnedToCore(writer,"storage",8192,nullptr,2,nullptr,0)!=pdPASS) {
    vTaskDelete(acquisition); Serial.println("startup:fault:storage-task"); return;
  }
  if (xTaskCreatePinnedToCore(animator,"rgb",4096,nullptr,1,nullptr,0)!=pdPASS) {
    xEventGroupSetBits(events,FAULT); Serial.println("startup:fault:rgb-task"); return;
  }
  Serial.println("ready:press-to-toggle;sync-not-implemented");
}
void loop() { vTaskDelay(pdMS_TO_TICKS(1000)); }

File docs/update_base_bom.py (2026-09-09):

"""Render procurement draft from current compiler-generated pcb/bom.csv.
Preserve prior exact-part links, never inherit Sense/battery links for replacements.
"""
import csv
import re
from pathlib import Path

root = Path(__file__).resolve().parents[1]
old = (root / 'pcb/backups/pre-base-redesign/bom.md').read_text()
rows = list(csv.DictReader((root / 'pcb/bom.csv').open()))
lines = ['# Base-XIAO audio carrier — procurement BOM (DRAFT)', '',
         '**Not released for purchase/assembly.** Supersedes the Sense/603450/RGB BOM.',
         'Generated from `pcb/bom.csv`; electrical source refs may differ from physical KiCad refs.',
         'Prior BOM and historical prices: `pcb/backups/pre-base-redesign/bom.md`.',
         'No live stock or prices checked in this revision. See [validation and GPIO map](base-redesign.md).', '',
         '## Carrier PCB components', '',
         '| Qty | Source refs | MPN | Value / function | Existing sourcing link |',
         '|---:|---|---|---|---|']
for r in rows:
    mpn = r['MPN']
    if not mpn:
        continue
    urls = []
    for line in old.splitlines():
        if mpn in line:
            urls = re.findall(r'\[[^]]+\]\((https?://[^\s]+)\)', line)
            if urls:
                break
    refs = []
    for path in r.get('Zener Paths','').split(' | '):
        if '<root>.' in path:
            refs.append(path.split('<root>.')[1].split('.')[0])
    link = f'[existing supplier]({urls[0]})' if urls else '**Link needed**'
    if mpn == '113991114':
        link = '[Seeed base board](https://www.seeedstudio.com/XIAO-ESP32S3-p-5627.html); India supplier link needed'
    lines.append(f"| {r['Quantity']} | {' / '.join(refs) or r['References']} | {mpn} | {r['Value'] or r['Package']} | {link} |")
lines += ['', '## Off-board / assembly procurement', '',
          '| Qty | Item | Requirement / source status |', '|---:|---|---|',
          '| 1 | BAT1 protected 1S LiPo, exact MPN TBD | 300–500 mAh, 11–18 mm finished width, <=4–5.5 mm thick, 45–65 mm long; >=500 mA continuous plus documented pulse, 4.20 V charge, PCM, preferred 10k NTC. **New link and manufacturer drawing required.** |',
          '| 1 | SPK1 Same Sky CMS-16093-078L100 | Retained provisionally, 8 ohm / 0.7 W; existing Mouser link in archived BOM. R24 selects 3 dB gain; output limit and cavity bench validation required. |',
          '| 1 | M1 exact vibration motor TBD | Old Robu 1027 URL served 1034. **Replacement exact link with start/stall current and dimensions required.** Must tolerate regulated 3.3 V. |',
          '| 1 | microSD card, exact MPN/capacity TBD | Prefer traceable high-endurance 16–32 GB FAT32 for prototype; **link needed**. Qualify write latency and peak/standby current. |',
          '| 1 set | Battery, speaker and motor harnesses | J1/J3 PH 2 mm, J2 SH 1 mm; confirm polarity, wire length, connector orientation. Motor PH pigtail has prior Sunrom link; **exact battery/speaker mating leads needed**. |',
          '| 1 set | Microphone acoustic gasket / dust mesh | **Supplier links needed**, thickness and acoustic impedance TBD after port design. |',
          '| 1 | XIAO-compatible 2.4 GHz antenna | Confirm supplied with base SKU; otherwise exact antenna link/drawing needed. |',
          '', '## Changes and purchasing cautions', '',
          '- Removed Sense 113991115 expansion/camera/SD/mic assembly, camera mechanics, NOVA 603450 battery, PCA9685, two RGB LEDs, C6 and R9–R14.',
          '- Added base 113991114, candidate IM69D130V01XTSA1, DM3D-SF socket, C9/C10/C11, R16–R24.',
          '- New unique resistors needing links: RC0603FR-0733RL (33 ohm, 2 pcs), RC0603FR-0747KL (47k, 5 pcs).',
          '- AP2112K-3.3TRG1 was already in the circuit but lacks a saved sourcing link.',
          '- Additional 100nF/10uF/100k parts reuse existing MPN links; no new passive selection needed for those.',
          '- H1–H4 and TP3/TP4 are PCB features, not purchased components. Mounting hardware remains mechanical-design TBD.',
          '- Flyback D1 cathode is MOTOR_3V3, NOT VBAT. Speaker terminals are differential, neither grounded.',
          '- J1/J3 through-hole PH headers and SW2 remain provisional thickness risks.',
          '- No external RGB indication. Base board GPIO21 user LED is reused.',
          '- Candidate microphone package/electrical review and socket land-pattern/no-trace regions are unresolved; do not substitute or freeze layout from this draft.', '']
(root / 'docs/bom.md').write_text('\n'.join(lines))

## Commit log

2026-09-08 Update mechanical CAD battery reserve and tail clearance, add silk review scripts
    [layout.kicad_pcb]
2026-09-08 Add comprehensive BOM and datasheet references for new components
    [bom.csv, bosch-bmi270-lga-14-3x2.5mm.step, generic-c-0603-1608metric.step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]
2026-09-08 Add compact redesign documentation and reference envelopes
    [bat1-provisional-envelope.step, bom.csv, pts841gk-body-only.step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]
2026-09-08 Add comprehensive BOM, redesign docs, and updated CAD files
    [bom.csv, compact-pendant-fit-prototype.step, front-battery-pendant.step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]
2026-09-09 Add comprehensive BOM and redesign documentation for new components
    [bom.csv, layout.kicad_pcb]
2026-09-12 Update design docs, BOM, and mechanical references for Adafruit 1578 battery
    [bom.csv]
2026-09-12 Add Adafruit 1578 battery tray and update BOM and docs
    [pendant-battery-tray-adafruit-1578.step]
2026-09-13 Add RGB matrix support and update platformio configuration
    [bom.csv, layout.kicad_pcb]
2026-09-14 Add TPS2553 power switch component and update BOM and platformio config
2026-09-15 Update BOM, docs, and platformio for new power switch and RGB matrix
    [bom.csv]
2026-09-17 Add compact placement candidate and update BOM, layout, and component library
    [before.kicad_pcb, bom.csv, layout.kicad_pcb]
2026-09-17 Clean up mechanical archive and update README
    [bat1-provisional-envelope.step, bosch-bmi270-lga-14-3x2.5mm.step, compact-pendant-fit-prototype.step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]
2026-09-17 Add compact rear‑ESP candidate and update mechanical, BOM, and layout
    [before.kicad_pcb, layout.kicad_pcb, populated-pcb-with-pads.step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]
2026-09-17 Revise eyelet to slim side‑profile U‑loop with X‑directed chain
    [layout.kicad_pcb, layout.kicad_sch]
2026-09-21 Update board configuration, BOM, and documentation for new XIAO ESP32S3
    [layout.dsn, layout.first-pass.kicad_pcb, layout.input-with-partial-copper.kicad_pcb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]
2026-09-21 Remove stale artifacts and document current validation
    [before.kicad_pcb, bom.csv, layout.dsn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]
